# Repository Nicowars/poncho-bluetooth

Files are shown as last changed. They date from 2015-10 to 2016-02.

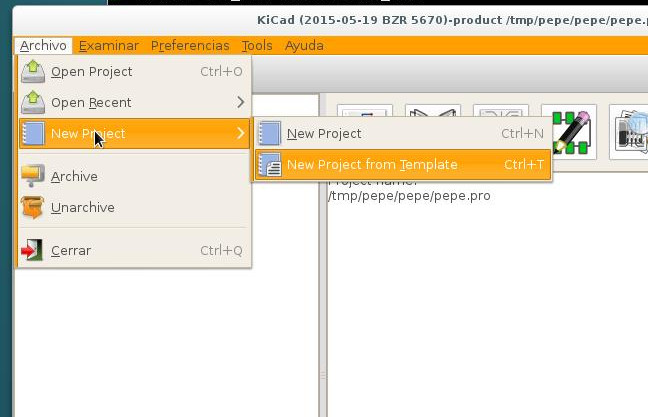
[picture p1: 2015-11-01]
Poncho/modelos/doc/screen1.jpg

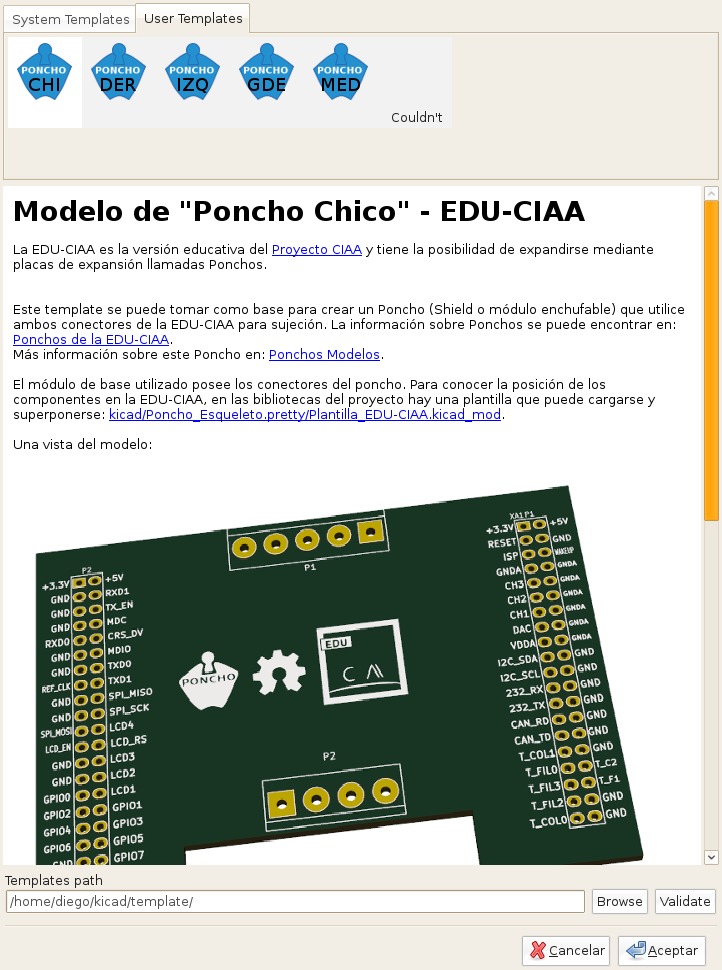
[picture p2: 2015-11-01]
Poncho/modelos/doc/screen5.jpg

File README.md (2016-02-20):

# poncho-bluetooth
Repositorio para el desarrollo de un Poncho que implementa Bluetooth para la EDU-CIAA

Para poder utilizarse correctamente el proyecto, debe sobreescribirse el archivo ubicado en /modules/drivers/cortexM4/lpc43xx/lpc4337/src/ciaaDriverDio.c del Firmware de la CIAA por el que esta incluido en projects/Firmware. Luego debe recompilarse el Firmware.

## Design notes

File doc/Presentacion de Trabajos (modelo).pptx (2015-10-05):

## Ingeniería en Computación Taller de Proyecto I [E0306]

Presentación Informe Inicial:
Título: Poncho Bluetooth
Fecha: 05/OCT/2015
Grupo 6
Integrantes:
1.- Laurella, Nicolás 4.- Solito, Manuel
2.- Morgillo, Gabriel 5.- Zubieta Battista, Jaime
3.- Muriel, Alex

## Presentación:

- 1.- Propuesta.
- 2.- Descripción del proyecto
- 3.- Materiales a utilizar
- 4.- Diagrama en Bloques del Sistema
- 5.- Explicación funcional
- 6.- Cronograma

Taller de Proyectos I

## Propuesta (1/2):

- Motivación:
Actualmente muchas aplicaciones requieren comunicación inalámbrica con dispositivos externos, por lo que consideramos fundamental agregar esta funcionalidad a la EDU-CIAA.
Por ejemplo el sistema de mando de un drone.

## Propuesta (2/2):

- Objetivos primarios: Diseñar e implementar una interfaz de bluetooth sobre una PCB compatible con la EDU-CIAA y desarrollar su respectivo controlador.
- Objetivos secundarios: Controlar los LEDs incluidos en la EDU-CIAA via Bluetooth desde una aplicación Android

## Materiales a utilizar (1/2):

Dispositivos:
- Chip Bluetooth RN4020 de Microchip
- U$S 18,50
- Proveedor: Elemon
- Versión Bluetooth 4.1
- Rango de Voltage 3.0V to 3.6V (3.3V)
- Rango de Temperatura: -30°C to 85°C
- Bajo consumo
  - Sleep <5.0 uA
  - Idle <1.5 mA
  - Active 16 mA a 0 dBm
- Interface UART
- Antena PCB incluida

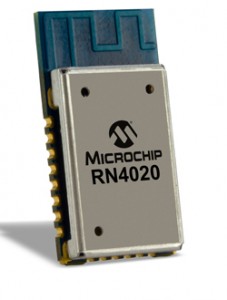
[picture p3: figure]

## Materiales a utilizar (2/2):

Componentes:
- 1 led verde
- 1 led azul
- 1 led rojo
- 3 resistencias de 330 Ohm
- 1 capacitor de Tantalio de 4,7 uF

## Diagrama de bloques (1/2)

PCB

RN4020

EDU-CIAA

UART

Otros

Referencia LEDs
- Led Rojo
Eventualidad
Encendido: Datos pendientes a ser recibidos
- Led Verde
Estado de conexión
Encendido: Conectado a un dispositivo
- Led Azul
Actividad
Encendido: Awake / en uso
Apagado: Sleep

LEDs

## Diagrama de bloques (2/2)

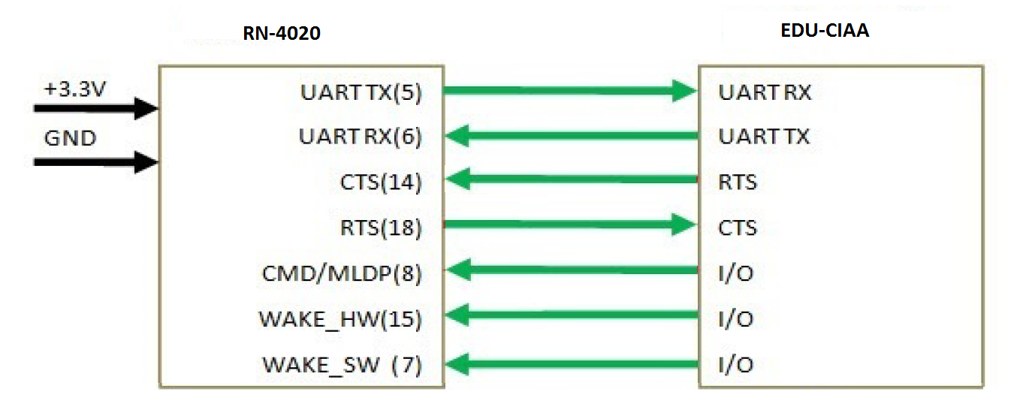
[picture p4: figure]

(RS232 RX)
(RS232 TX)

(GPIO)
(GPIO)
(GPIO)
(GPIO)
(GPIO)

Taller de Proyecto I

## Diagrama Esquemático:

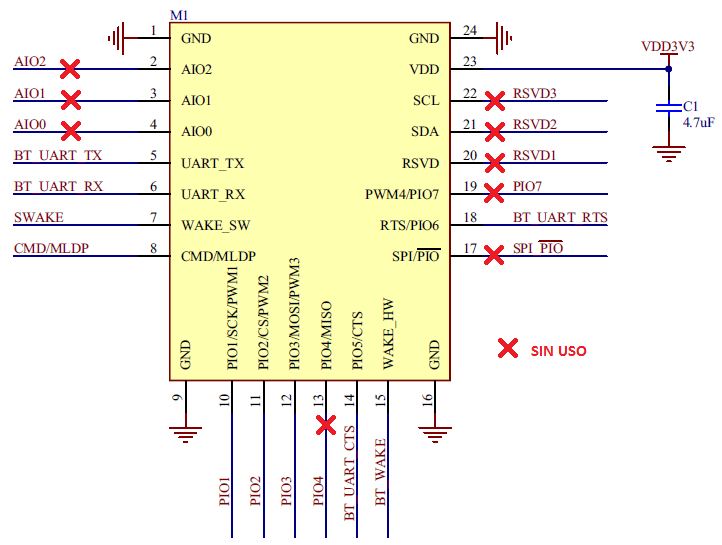
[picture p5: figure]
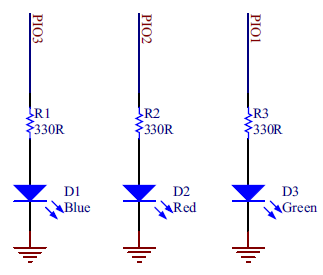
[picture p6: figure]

## Explicación funcional del Hardware y Software:

• Se realizará una aplicación Android para controlar vía Bluetooth los LEDs de la EDU-CIAA.
• La aplicación tendrá 3 botones para prender y apagar cada LED.
• Y además tendrá 3 barras deslizante para controlar la intensidad de cada color del LED RGB.

## Cronograma de Trabajo:

| Descripción | Fecha inicio | Fecha fin
Anteproyecto | Se analizan las propuestas y se fijan los objetivos | 10/08 | 16/08
Proyecto | Planeamiento y organización de las tareas a realizar | 17/08 | 13/09
Aprovisionamiento | Compra de los materiales requeridos | 14/09 | 09/10
Presentación del Proyecto | Presentación en clase del proyecto a realizar | 05/10 | 05/10
Diseño | Diseño de la placa PCB en KiCad® | 10/10 | 23/10
Prototipado | Implementación física de la unidad diseñada | 26/10 | 06/11
Controlador | Desarrollo del Firmware | 07/11 | 27/11
Testeo | Se prueba el correcto funcionamiento del Poncho | 28/11 | 04/12

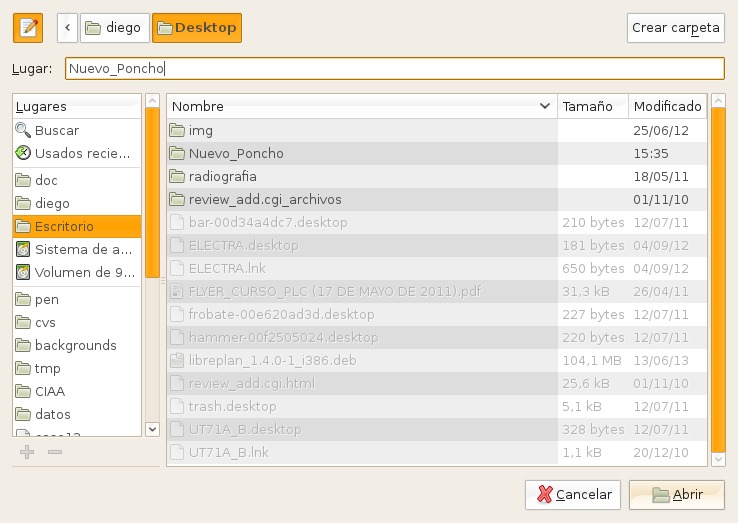
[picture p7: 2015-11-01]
Poncho/modelos/doc/screen2.jpg

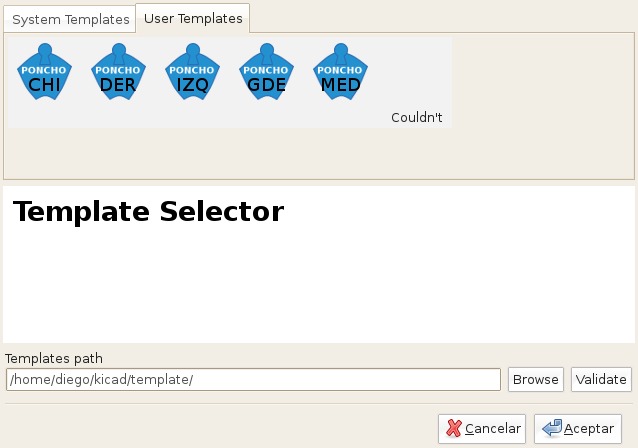
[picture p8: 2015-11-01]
Poncho/modelos/doc/screen4.jpg

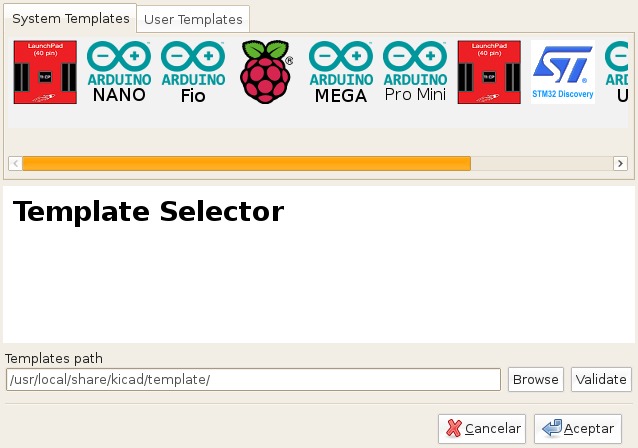
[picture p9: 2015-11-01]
Poncho/modelos/doc/screen3.jpg

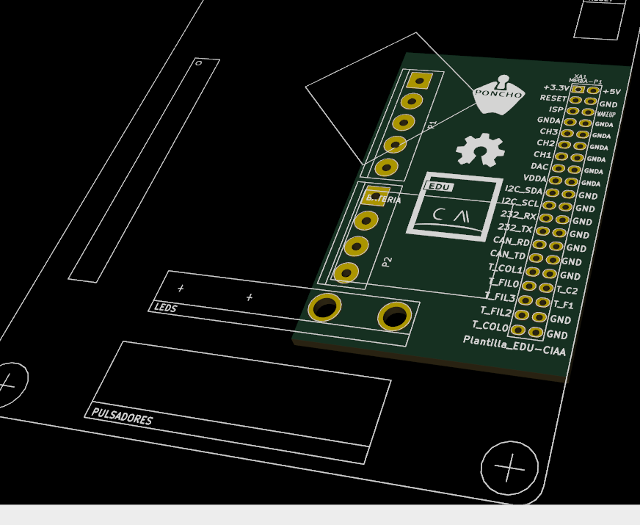
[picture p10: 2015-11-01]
Poncho/modelos/Poncho_Derecho/meta/ponchoF.png

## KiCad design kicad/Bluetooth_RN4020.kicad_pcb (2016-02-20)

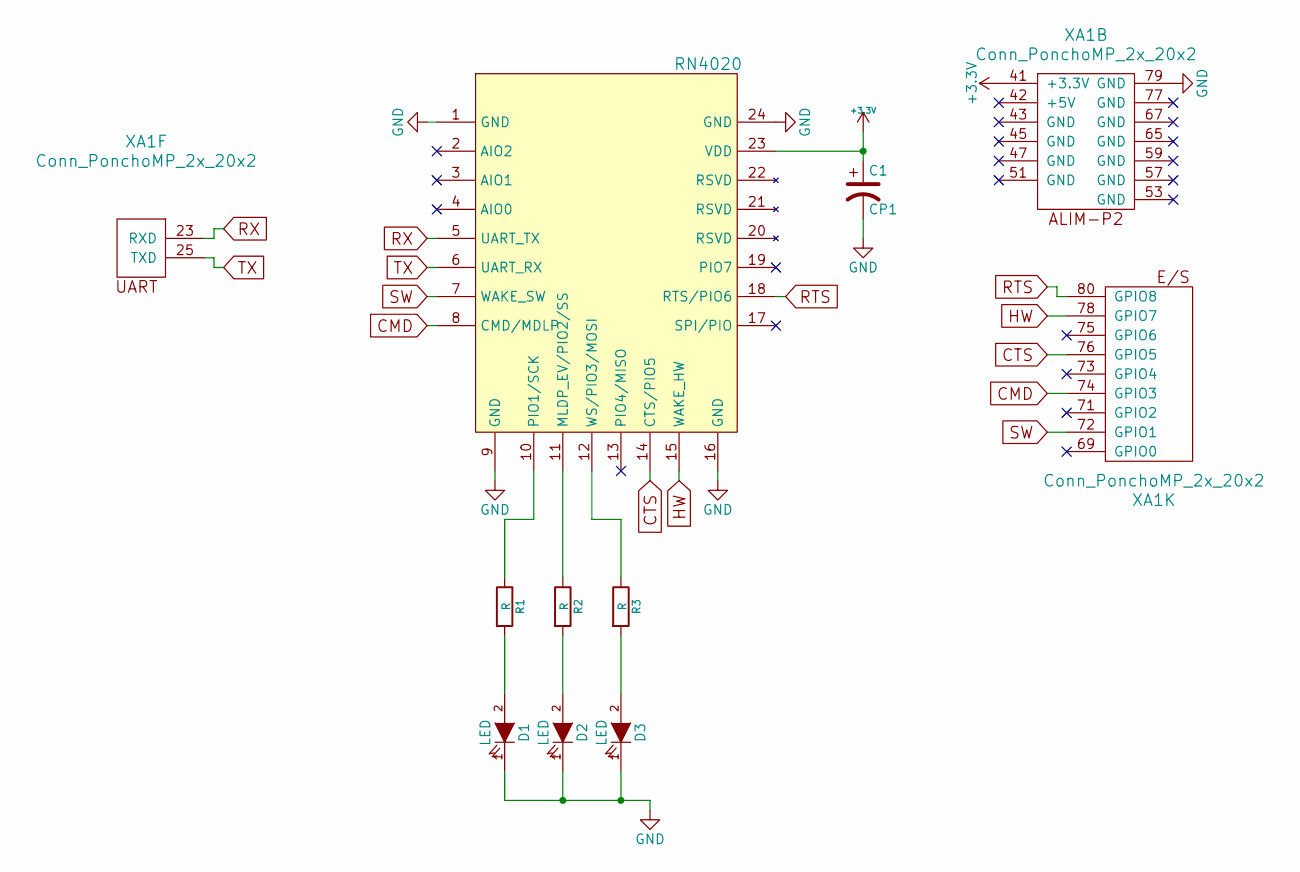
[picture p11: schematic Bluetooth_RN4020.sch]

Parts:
C1: CP1; TantalC_SizeB_EIA-3528_Reflow
D1, D2, D3: LED; LED-3MM
R1, R2, R3: R; R_1206
U1: RN4020
XA1: Conn_PonchoMP_2x_20x2

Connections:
+3V3: C1.1, U1.23 (VDD), XA1.41 (+3.3V)
CMD: U1.8 (CMD/MDLP), XA1.74 (GPIO3)
CTS: U1.14 (CTS/PIO5), XA1.76 (GPIO5)
GND: C1.2, D1.1 (K), D2.1 (K), D3.1 (K), U1.1 (GND), U1.9 (GND), U1.16 (GND), U1.24 (GND), XA1.79 (GND)
HW: U1.15 (WAKE_HW), XA1.78 (GPIO7)
unnamed: D1.2 (A), R1.2
unnamed: D2.2 (A), R2.2
unnamed: D3.2 (A), R3.2
unnamed: R1.1, U1.10 (PIO1/SCK)
unnamed: R2.1, U1.11 (MLDP_EV/PIO2/SS)
unnamed: R3.1, U1.12 (WS/PIO3/MOSI)
RTS: U1.18 (RTS/PIO6), XA1.80 (GPIO8)
RX: U1.5 (UART_TX), XA1.23 (RXD)
SW: U1.7 (WAKE_SW), XA1.72 (GPIO1)
TX: U1.6 (UART_RX), XA1.25 (TXD)

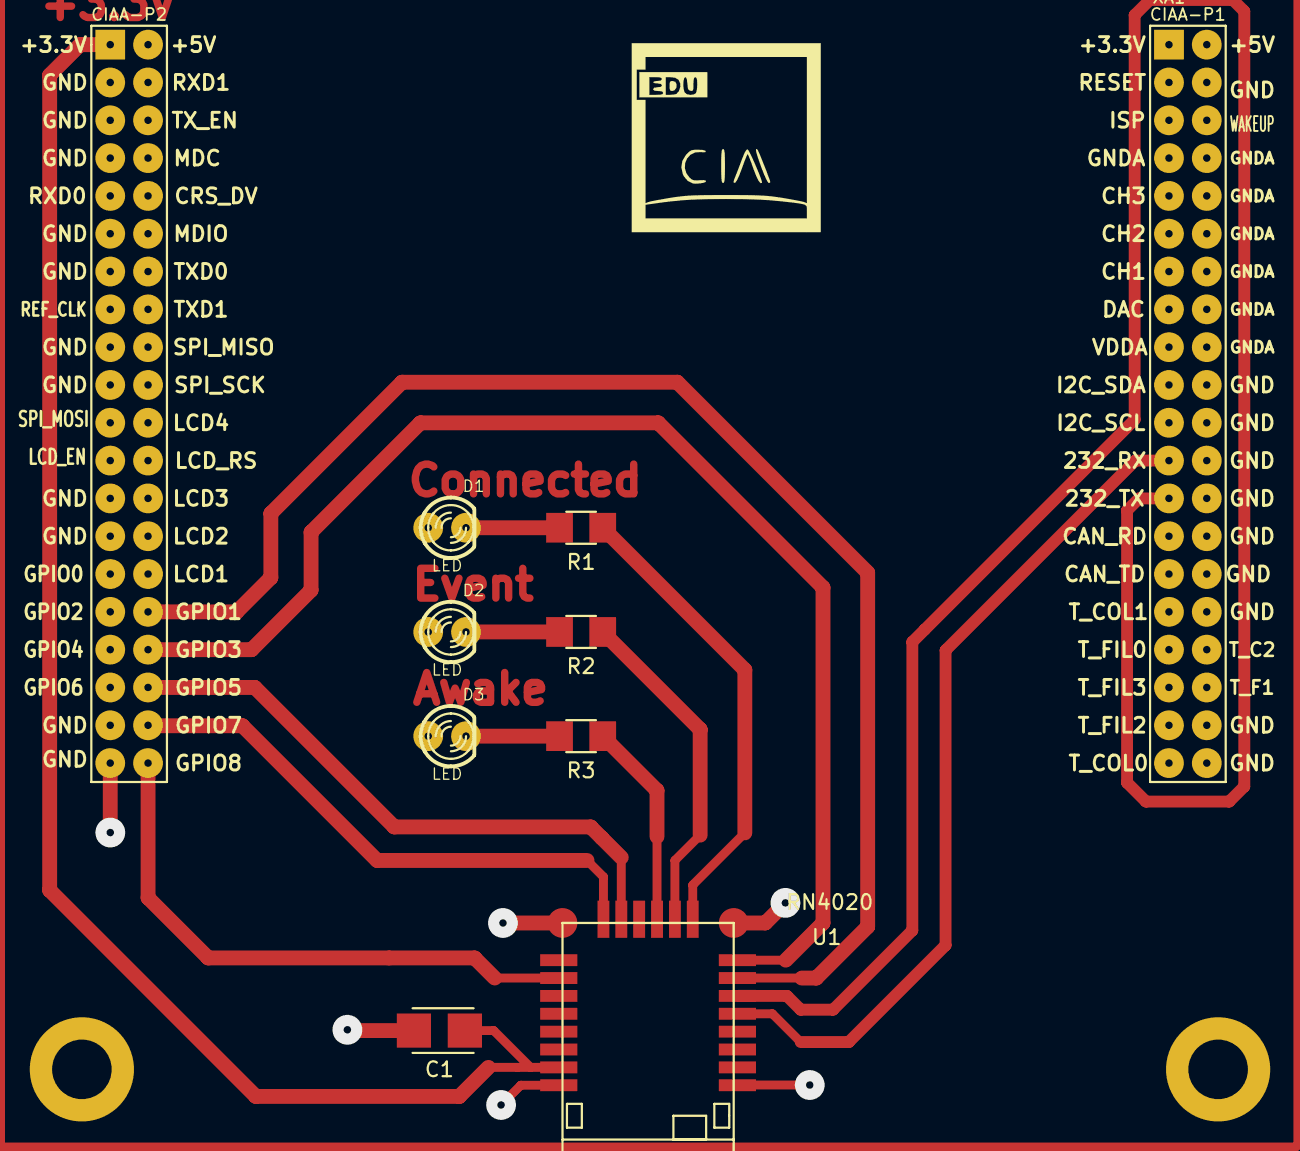
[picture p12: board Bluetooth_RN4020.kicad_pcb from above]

Board: 2 copper layers, 9 parts (0 on the bottom side), 15 nets.

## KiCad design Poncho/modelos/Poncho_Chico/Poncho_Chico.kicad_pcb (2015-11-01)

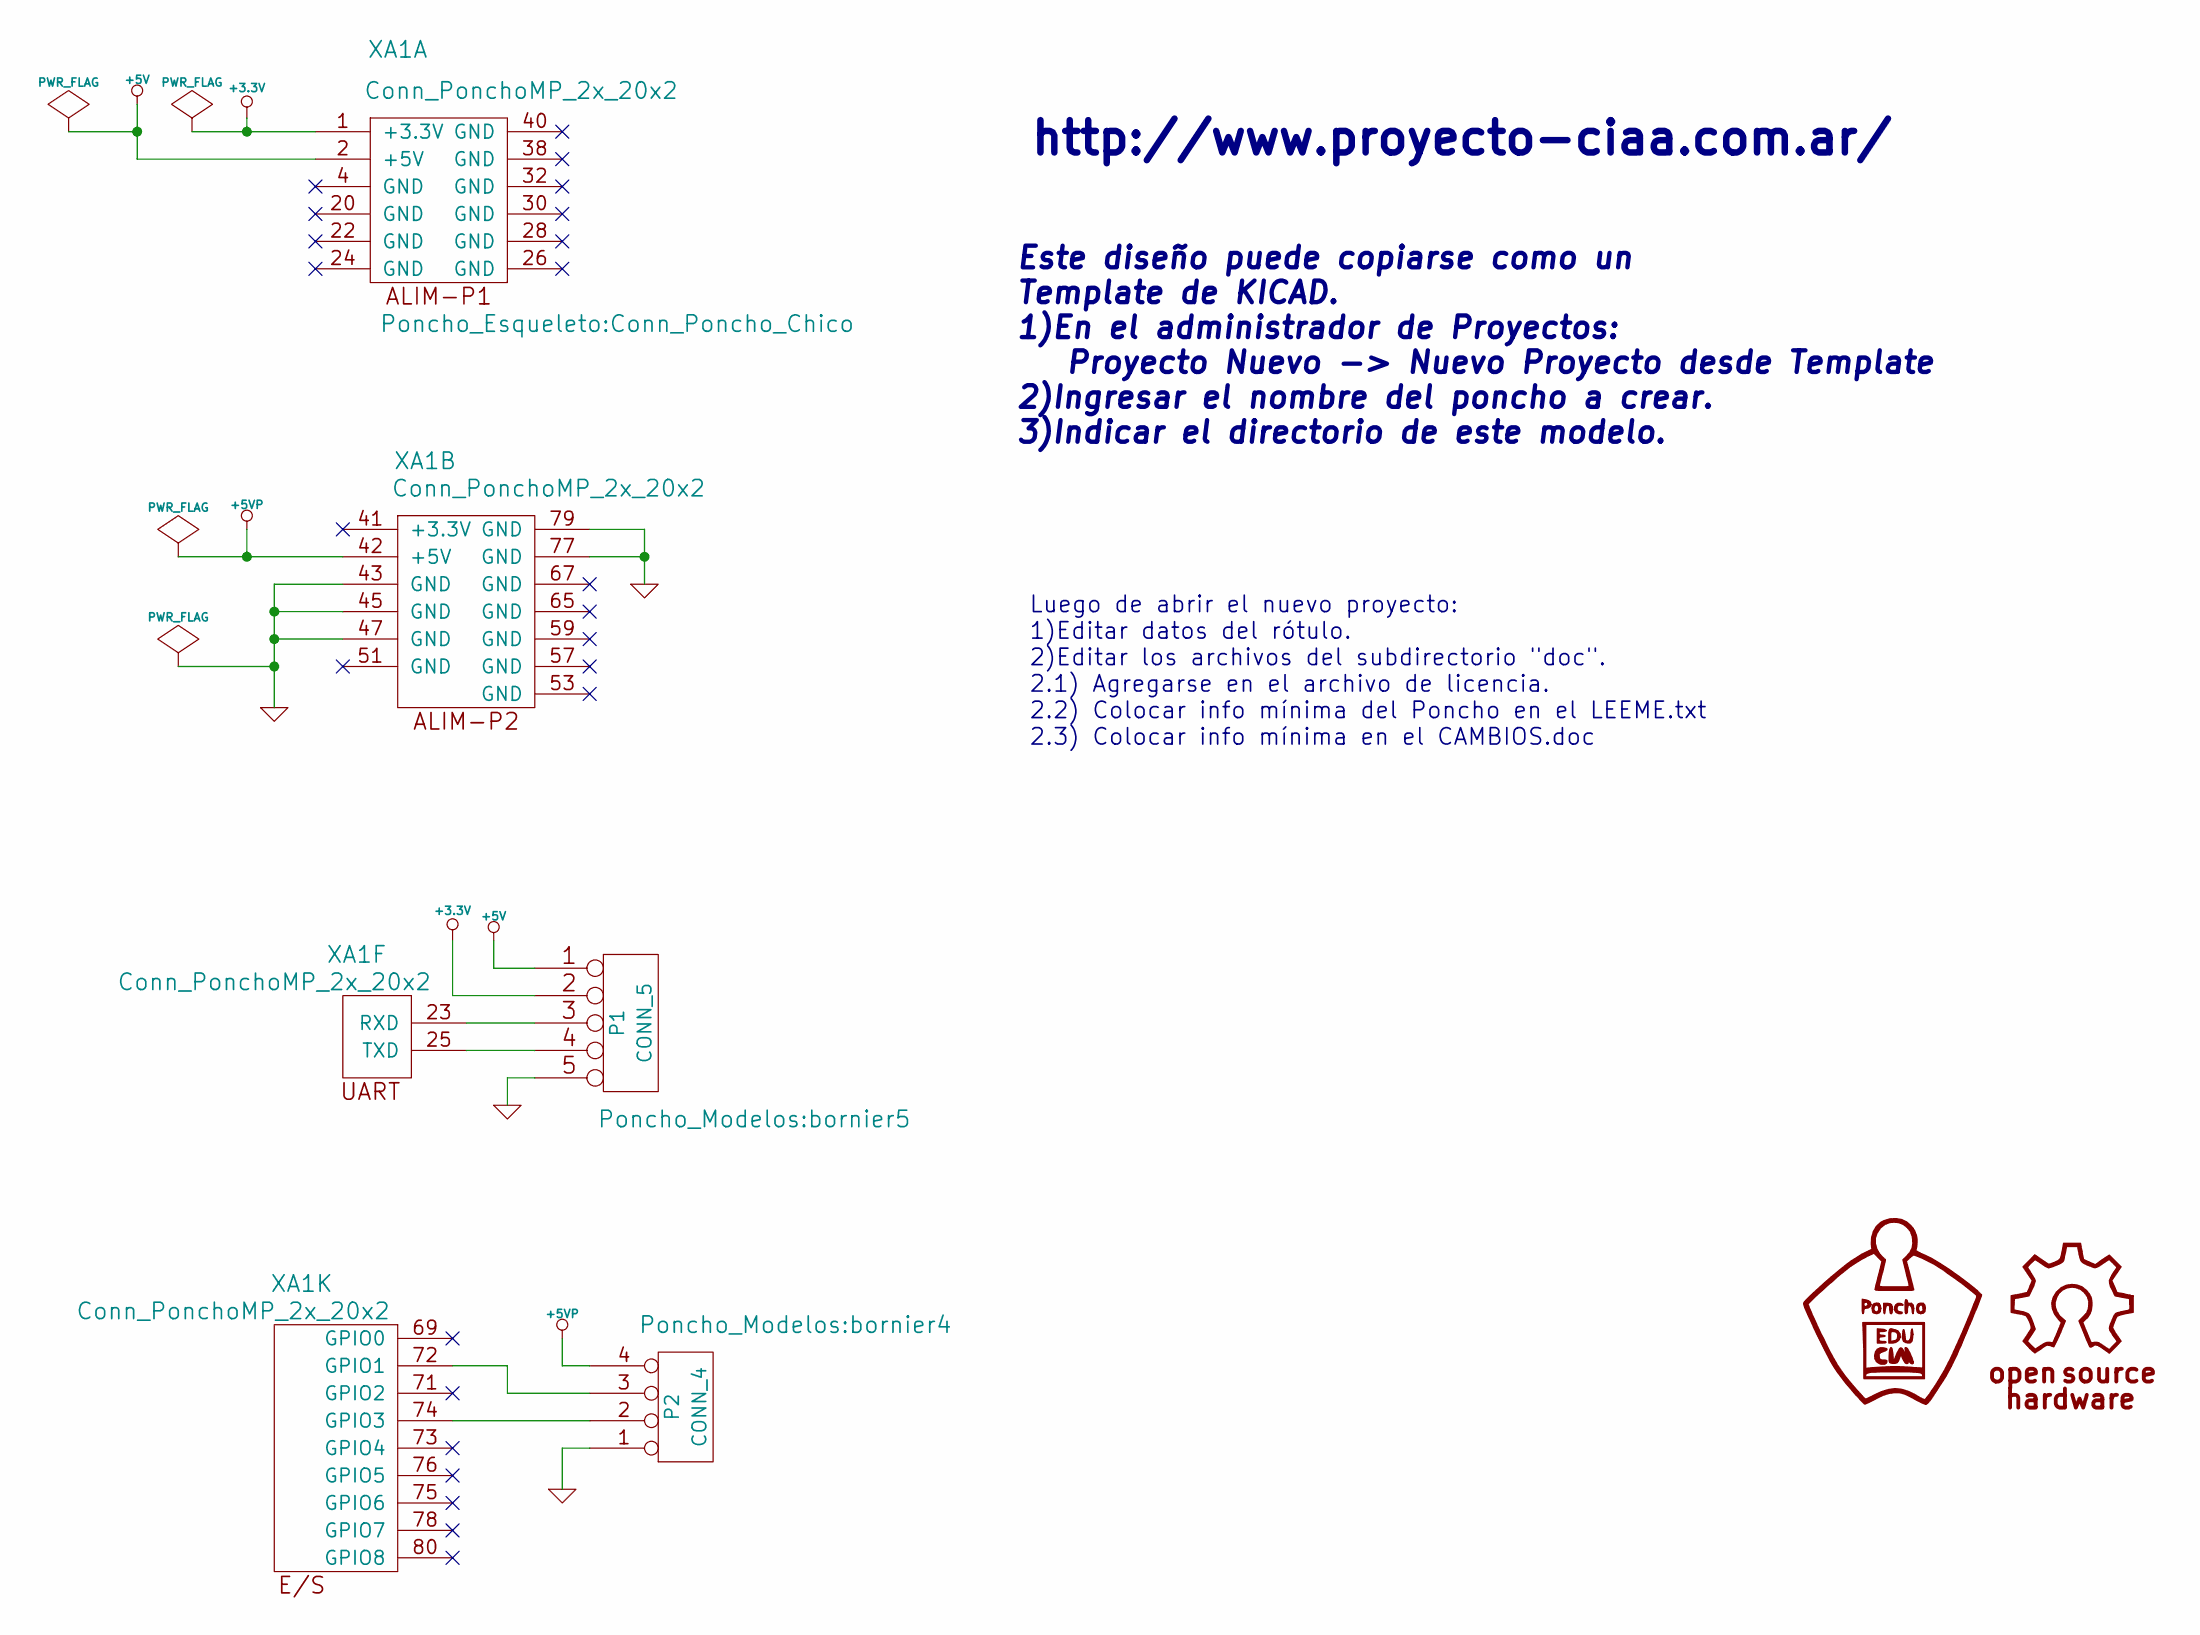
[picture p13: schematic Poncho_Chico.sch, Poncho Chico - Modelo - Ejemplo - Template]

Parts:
P1: CONN_5; bornier5
P2: CONN_4; bornier4
XA1: Conn_PonchoMP_2x_20x2; Conn_Poncho_Chico

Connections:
+3.3V: P1.2, XA1.1 (+3.3V)
+5V: P1.1, XA1.2 (+5V)
+5VP: P2.4, XA1.42 (+5V)
GND: P1.5, P2.1, XA1.43 (GND), XA1.45 (GND), XA1.47 (GND), XA1.77 (GND), XA1.79 (GND)
unnamed: P1.3, XA1.23 (RXD)
unnamed: P1.4, XA1.25 (TXD)
unnamed: P2.2, XA1.74 (GPIO3)
unnamed: P2.3, XA1.72 (GPIO1)

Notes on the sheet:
Este diseño puede copiarse como un Template de KICAD. 1)En el administrador de Proyectos: Proyecto Nuevo -> Nuevo Proyecto desde Template 2)Ingresar el nombre del poncho a crear. 3)Indicar el directorio de este modelo.
http://www.proyecto-ciaa.com.ar/
Luego de abrir el nuevo proyecto: 1)Editar datos del rótulo. 2)Editar los archivos del subdirectorio "doc". 2.1) Agregarse en el archivo de licencia. 2.2) Colocar info mínima del Poncho en el LEEME.txt 2.3) Colocar info mínima en el CAMBIOS.doc

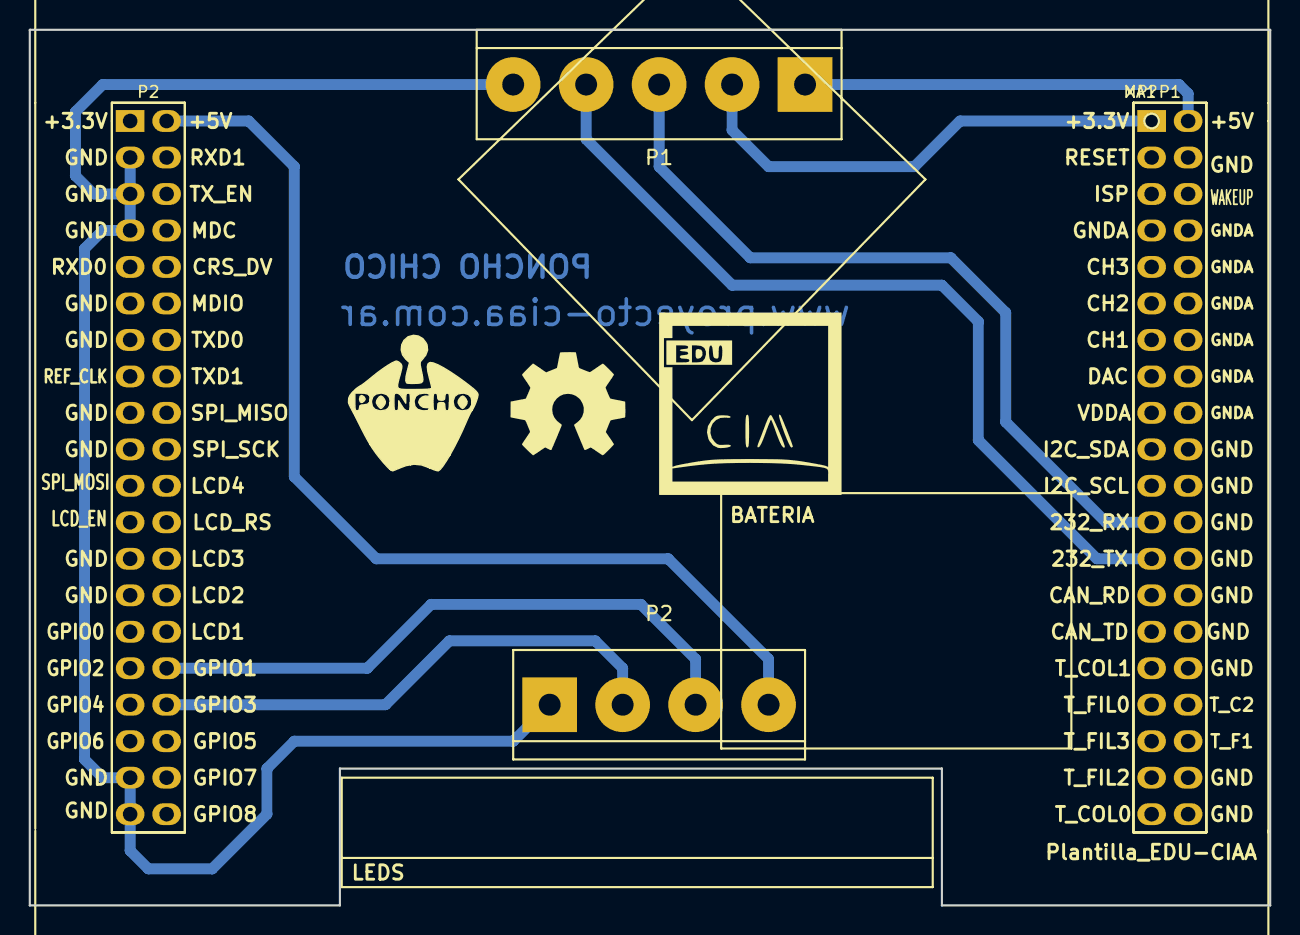
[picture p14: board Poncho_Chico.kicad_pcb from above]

Board: 2 copper layers, 86.4 x 61.0 mm, 5 parts (0 on the bottom side), 8 nets.

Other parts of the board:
G101: Logo_OSHWA
MP?: Plantilla_EDU-CIAA

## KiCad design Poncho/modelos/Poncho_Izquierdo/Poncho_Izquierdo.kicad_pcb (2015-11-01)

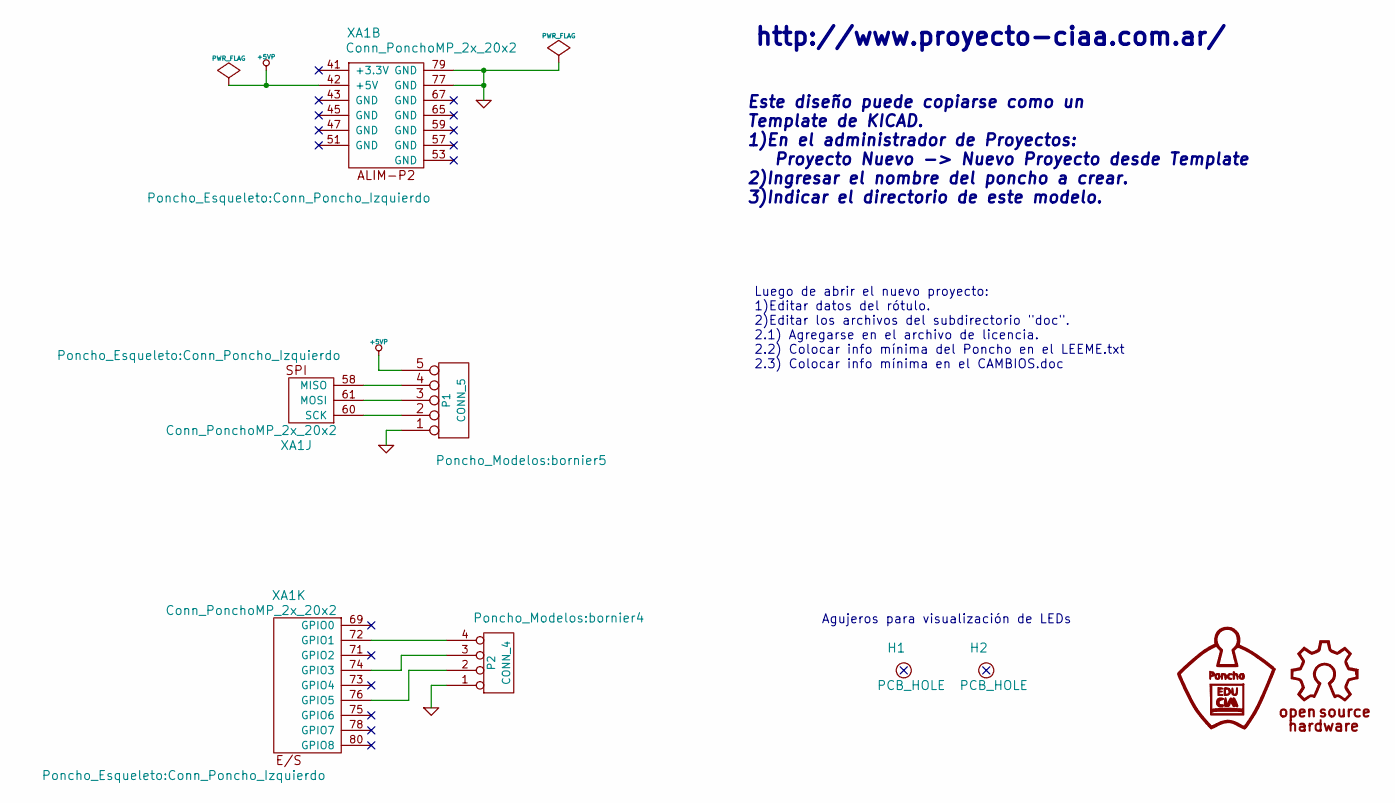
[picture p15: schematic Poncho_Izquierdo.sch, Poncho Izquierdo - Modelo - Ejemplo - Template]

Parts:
H1, H2: PCB_HOLE; Led_Hole
P1: CONN_5; bornier5
P2: CONN_4; bornier4
XA1: Conn_PonchoMP_2x_20x2; Conn_Poncho_Izquierdo

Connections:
+5VP: P1.5, XA1.42 (+5V)
GND: P1.1, P2.1, XA1.77 (GND), XA1.79 (GND)
unnamed: P1.2, XA1.60 (SCK)
unnamed: P1.3, XA1.61 (MOSI)
unnamed: P1.4, XA1.58 (MISO)
unnamed: P2.2, XA1.76 (GPIO5)
unnamed: P2.3, XA1.74 (GPIO3)
unnamed: P2.4, XA1.72 (GPIO1)

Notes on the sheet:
Este diseño puede copiarse como un Template de KICAD. 1)En el administrador de Proyectos: Proyecto Nuevo -> Nuevo Proyecto desde Template 2)Ingresar el nombre del poncho a crear. 3)Indicar el directorio de este modelo.
http://www.proyecto-ciaa.com.ar/
Luego de abrir el nuevo proyecto: 1)Editar datos del rótulo. 2)Editar los archivos del subdirectorio "doc". 2.1) Agregarse en el archivo de licencia. 2.2) Colocar info mínima del Poncho en el LEEME.txt 2.3) Colocar info mínima en el CAMBIOS.doc
Agujeros para visualización de LEDs

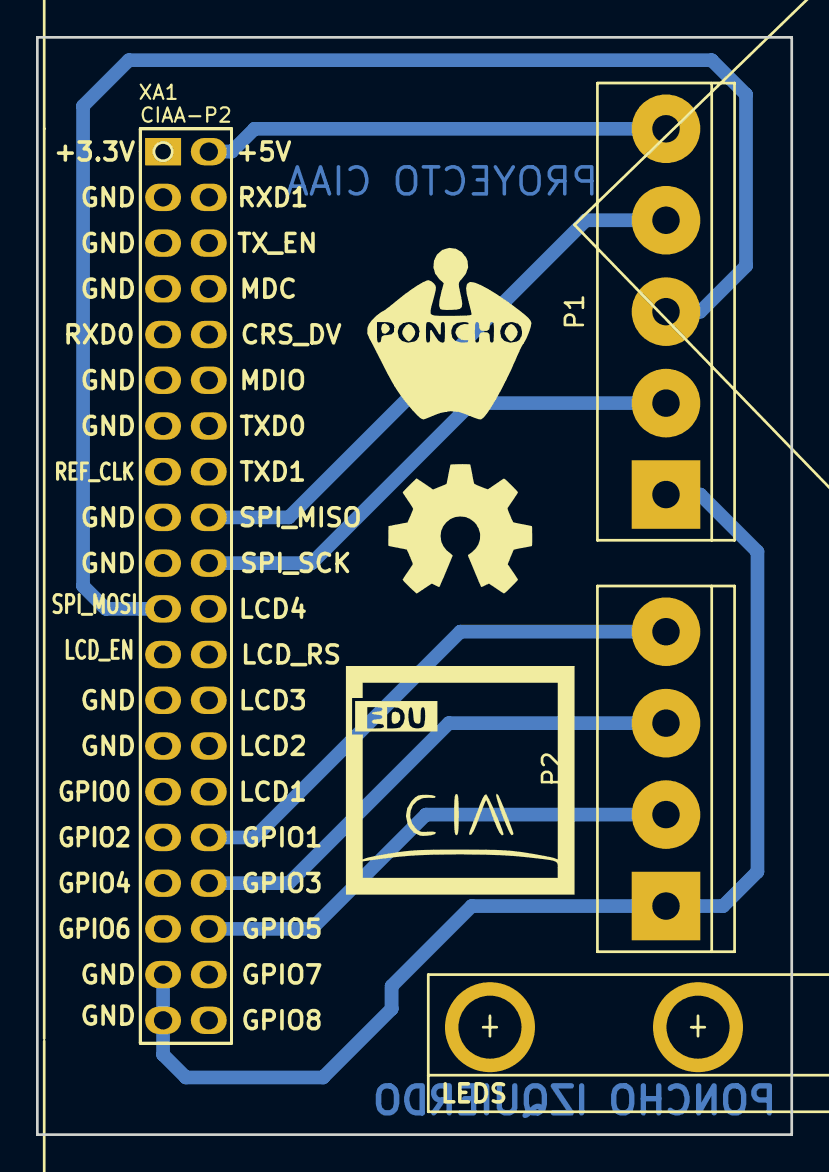
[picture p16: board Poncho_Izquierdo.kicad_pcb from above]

Board: 2 copper layers, 41.9 x 61.0 mm, 7 parts (0 on the bottom side), 8 nets.

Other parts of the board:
G101: Logo_OSHWA
MP1: Plantilla_EDU-CIAA

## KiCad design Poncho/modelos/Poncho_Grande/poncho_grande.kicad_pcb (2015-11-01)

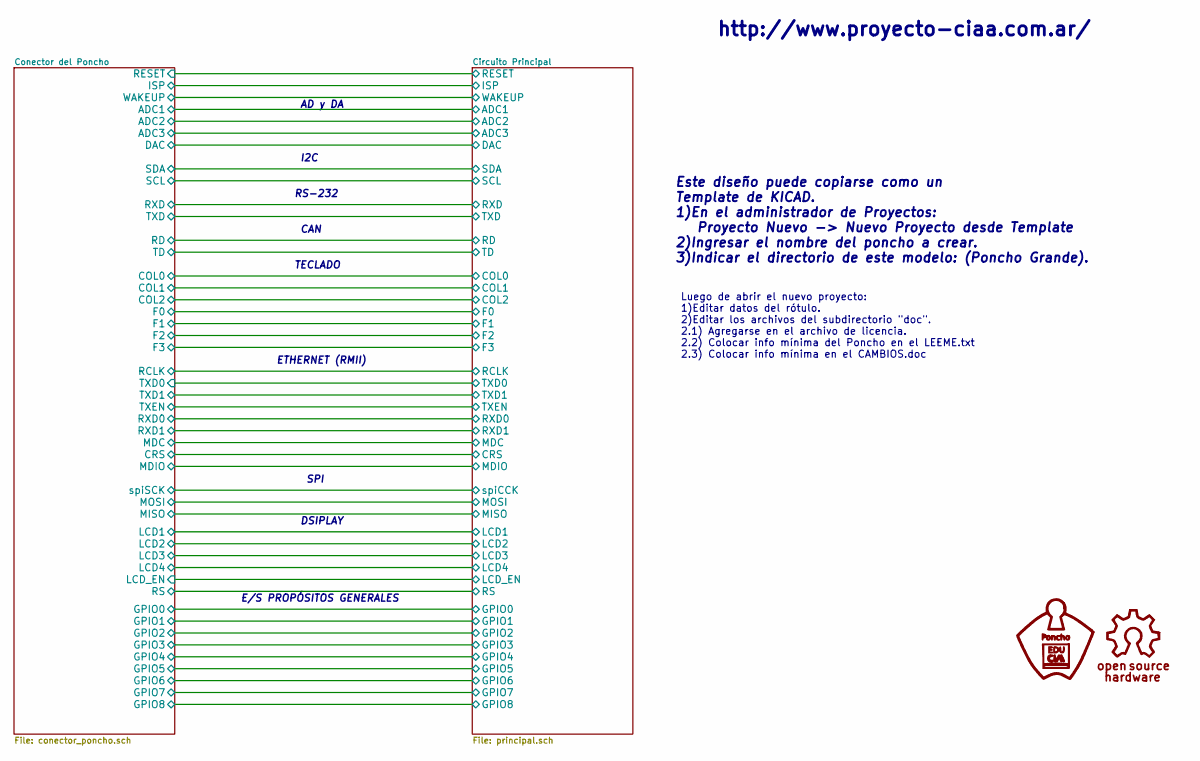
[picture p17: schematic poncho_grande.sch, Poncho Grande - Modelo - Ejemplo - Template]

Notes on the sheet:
AD y DA
I2C
RS-232
CAN
TECLADO
ETHERNET (RMII)
SPI
DSIPLAY
E/S PROPÓSITOS GENERALES
Este diseño puede copiarse como un Template de KICAD. 1)En el administrador de Proyectos: Proyecto Nuevo -> Nuevo Proyecto desde Template 2)Ingresar el nombre del poncho a crear. 3)Indicar el directorio de este modelo: (Poncho Grande).
http://www.proyecto-ciaa.com.ar/
Luego de abrir el nuevo proyecto: 1)Editar datos del rótulo. 2)Editar los archivos del subdirectorio "doc". 2.1) Agregarse en el archivo de licencia. 2.2) Colocar info mínima del Poncho en el LEEME.txt 2.3) Colocar info mínima en el CAMBIOS.doc

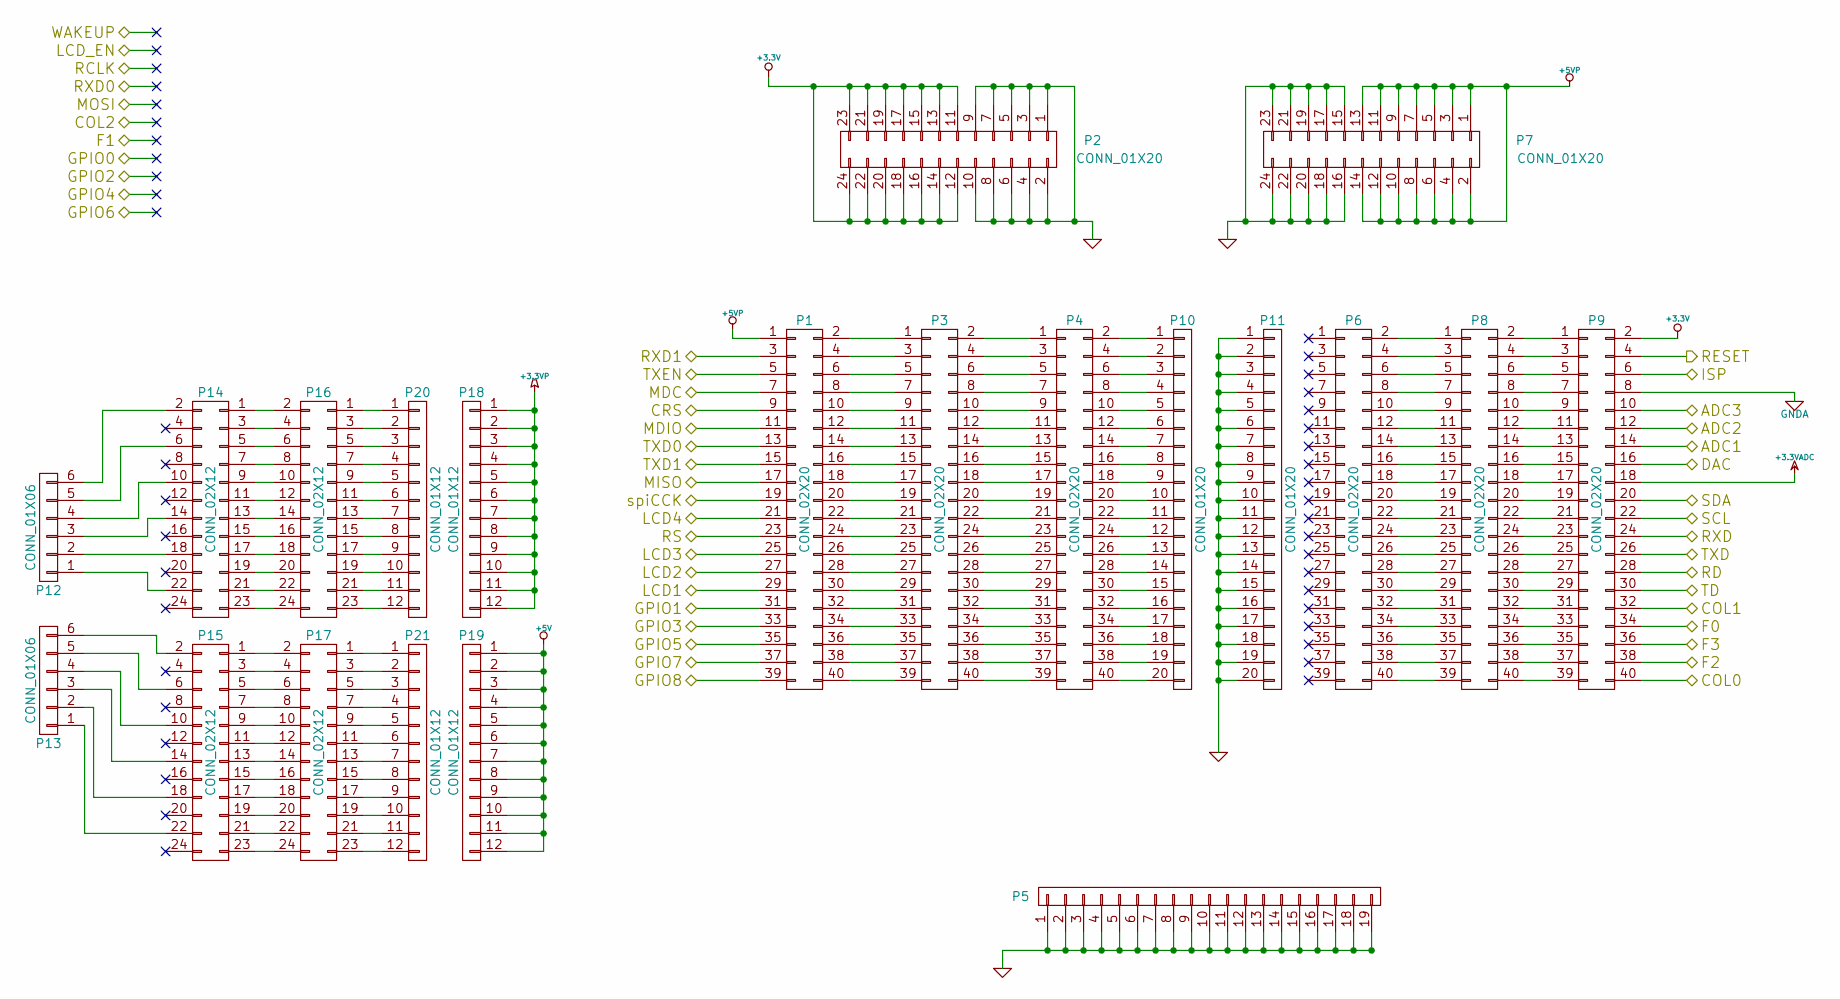
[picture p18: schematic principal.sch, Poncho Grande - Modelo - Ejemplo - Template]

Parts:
P1, P3, P4, P6, P8, P9: CONN_02X20; Pin_Header_Straight_2x20
P2, P7: CONN_01X20; Pin_Header_Straight_2x12
P5: CONN_01X19; Pin_Header_Straight_1x19
P10, P11: CONN_01X20; Pin_Header_Straight_1x20
P12, P13: CONN_01X06; bornier6
P14, P15, P16, P17: CONN_02X12; Pin_Header_Straight_2x12
P18, P19, P20, P21: CONN_01X12; Pin_Header_Straight_1x12

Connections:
+3.3V: P2.11, P2.12, P2.13, P2.14, P2.15, P2.16, P2.17, P2.18, P2.19, P2.20, P2.21, P2.22, P2.23, P2.24, P9.2; also elsewhere on the board
+3.3VADC: P9.18; also elsewhere on the board
+3.3VP: P18.1, P18.2, P18.3, P18.4, P18.5, P18.6, P18.7, P18.8, P18.9, P18.10, P18.11, P18.12; also elsewhere on the board
+5V: P19.1, P19.2, P19.3, P19.4, P19.5, P19.6, P19.7, P19.8, P19.9, P19.10, P19.11, P19.12; also elsewhere on the board
+5VP: P1.1, P7.1, P7.2, P7.3, P7.4, P7.5, P7.6, P7.7, P7.8, P7.9, P7.10, P7.11, P7.12, P7.13, P7.14; also elsewhere on the board
/Circuito Principal/ADC1: P9.14; also elsewhere on the board
/Circuito Principal/ADC2: P9.12; also elsewhere on the board
/Circuito Principal/ADC3: P9.10; also elsewhere on the board
/Circuito Principal/COL0: P9.40; also elsewhere on the board
/Circuito Principal/COL1: P9.32; also elsewhere on the board
/Circuito Principal/CRS: P1.9; also elsewhere on the board
/Circuito Principal/DAC: P9.16; also elsewhere on the board
/Circuito Principal/F0: P9.34; also elsewhere on the board
/Circuito Principal/F2: P9.38; also elsewhere on the board
/Circuito Principal/F3: P9.36; also elsewhere on the board
/Circuito Principal/GPIO1: P1.31; also elsewhere on the board
/Circuito Principal/GPIO3: P1.33; also elsewhere on the board
/Circuito Principal/GPIO5: P1.35; also elsewhere on the board
/Circuito Principal/GPIO7: P1.37; also elsewhere on the board
/Circuito Principal/GPIO8: P1.39; also elsewhere on the board
/Circuito Principal/ISP: P9.6; also elsewhere on the board
/Circuito Principal/LCD1: P1.29; also elsewhere on the board
/Circuito Principal/LCD2: P1.27; also elsewhere on the board
/Circuito Principal/LCD3: P1.25; also elsewhere on the board
/Circuito Principal/LCD4: P1.21; also elsewhere on the board
/Circuito Principal/MDC: P1.7; also elsewhere on the board
/Circuito Principal/MDIO: P1.11; also elsewhere on the board
/Circuito Principal/MISO: P1.17; also elsewhere on the board
/Circuito Principal/RD: P9.28; also elsewhere on the board
/Circuito Principal/RESET: P9.4; also elsewhere on the board
/Circuito Principal/RS: P1.23; also elsewhere on the board
/Circuito Principal/RXD: P9.24; also elsewhere on the board
/Circuito Principal/RXD1: P1.3; also elsewhere on the board
/Circuito Principal/SCL: P9.22; also elsewhere on the board
/Circuito Principal/SDA: P9.20; also elsewhere on the board
/Circuito Principal/TD: P9.30; also elsewhere on the board
/Circuito Principal/TXD: P9.26; also elsewhere on the board
/Circuito Principal/TXD0: P1.13; also elsewhere on the board
/Circuito Principal/TXD1: P1.15; also elsewhere on the board
/Circuito Principal/TXEN: P1.5; also elsewhere on the board
/Circuito Principal/spiCCK: P1.19; also elsewhere on the board
GND: P2.1, P2.2, P2.3, P2.4, P2.5, P2.6, P2.7, P2.8, P2.9, P2.10, P5.1, P5.2, P5.3, P5.4, P5.5, P5.6, P5.7, P5.8, P5.9, P5.10, P5.11, P5.12, P5.13, P5.14, P5.15, P5.16, P5.17, P5.18, P5.19, P7.15, P7.16, P7.17, P7.18, P7.19, P7.20, P7.21, P7.22, P7.23, P7.24, P11.1, P11.2, P11.3, P11.4, P11.5, P11.6, P11.7, P11.8, P11.9, P11.10, P11.11, P11.12, P11.13, P11.14, P11.15, P11.16, P11.17, P11.18, P11.19, P11.20; also elsewhere on the board
GNDA: P9.8; also elsewhere on the board
unnamed: P1.2, P3.1
unnamed: P1.4, P3.3
unnamed: P1.6, P3.5
unnamed: P1.8, P3.7
unnamed: P1.10, P3.9
unnamed: P1.12, P3.11
unnamed: P1.14, P3.13
unnamed: P1.16, P3.15
unnamed: P1.18, P3.17
unnamed: P1.20, P3.19
unnamed: P1.22, P3.21
unnamed: P1.24, P3.23
unnamed: P1.26, P3.25
unnamed: P1.28, P3.27
unnamed: P1.30, P3.29
unnamed: P1.32, P3.31
unnamed: P1.34, P3.33
unnamed: P1.36, P3.35
unnamed: P1.38, P3.37
unnamed: P1.40, P3.39
unnamed: P3.2, P4.1
unnamed: P3.4, P4.3
unnamed: P3.6, P4.5
unnamed: P3.8, P4.7
unnamed: P3.10, P4.9
unnamed: P3.12, P4.11
unnamed: P3.14, P4.13
unnamed: P3.16, P4.15
unnamed: P3.18, P4.17
unnamed: P3.20, P4.19
unnamed: P3.22, P4.21
unnamed: P3.24, P4.23
unnamed: P3.26, P4.25
unnamed: P3.28, P4.27
unnamed: P3.30, P4.29
unnamed: P3.32, P4.31
unnamed: P3.34, P4.33
unnamed: P3.36, P4.35
unnamed: P3.38, P4.37
unnamed: P3.40, P4.39
unnamed: P6.2, P8.1
unnamed: P6.4, P8.3
unnamed: P6.6, P8.5
unnamed: P6.8, P8.7
unnamed: P6.10, P8.9
unnamed: P6.12, P8.11
unnamed: P6.14, P8.13
unnamed: P6.16, P8.15
unnamed: P6.18, P8.17
unnamed: P6.20, P8.19
unnamed: P6.22, P8.21
unnamed: P6.24, P8.23
unnamed: P6.26, P8.25
unnamed: P6.28, P8.27
unnamed: P6.30, P8.29
unnamed: P6.32, P8.31
unnamed: P6.34, P8.33
unnamed: P6.36, P8.35
unnamed: P6.38, P8.37
unnamed: P6.40, P8.39
unnamed: P8.2, P9.1
unnamed: P8.4, P9.3
unnamed: P8.6, P9.5
unnamed: P8.8, P9.7
unnamed: P8.10, P9.9
unnamed: P8.12, P9.11
unnamed: P8.14, P9.13
unnamed: P8.16, P9.15
unnamed: P8.18, P9.17
unnamed: P8.20, P9.19
unnamed: P8.22, P9.21
unnamed: P8.24, P9.23
unnamed: P8.26, P9.25
unnamed: P8.28, P9.27
unnamed: P8.30, P9.29
unnamed: P8.32, P9.31
unnamed: P8.34, P9.33
unnamed: P8.36, P9.35
unnamed: P8.38, P9.37
unnamed: P8.40, P9.39
unnamed: P4.2, P10.1
unnamed: P4.4, P10.2
unnamed: P4.6, P10.3
unnamed: P4.8, P10.4
unnamed: P4.10, P10.5
unnamed: P4.12, P10.6
unnamed: P4.14, P10.7
unnamed: P4.16, P10.8
unnamed: P4.18, P10.9
unnamed: P4.20, P10.10
unnamed: P4.22, P10.11
unnamed: P4.24, P10.12
unnamed: P4.26, P10.13
unnamed: P4.28, P10.14
unnamed: P4.30, P10.15
unnamed: P4.32, P10.16
unnamed: P4.34, P10.17
unnamed: P4.36, P10.18
unnamed: P4.38, P10.19
unnamed: P4.40, P10.20
unnamed: P12.1, P14.22
unnamed: P12.2, P14.18
unnamed: P12.3, P14.14
unnamed: P12.4, P14.10
unnamed: P12.5, P14.6
unnamed: P12.6, P14.2
unnamed: P13.1, P15.22
unnamed: P13.2, P15.18
unnamed: P13.3, P15.14
unnamed: P13.4, P15.10
unnamed: P13.5, P15.6
unnamed: P13.6, P15.2
unnamed: P14.1, P16.2
unnamed: P14.3, P16.4
unnamed: P14.5, P16.6
unnamed: P14.7, P16.8
unnamed: P14.9, P16.10
unnamed: P14.11, P16.12
unnamed: P14.13, P16.14
unnamed: P14.15, P16.16
unnamed: P14.17, P16.18
unnamed: P14.19, P16.20
unnamed: P14.21, P16.22
unnamed: P14.23, P16.24
unnamed: P15.1, P17.2
unnamed: P15.3, P17.4
unnamed: P15.5, P17.6
unnamed: P15.7, P17.8
unnamed: P15.9, P17.10
unnamed: P15.11, P17.12
unnamed: P15.13, P17.14
unnamed: P15.15, P17.16
unnamed: P15.17, P17.18
unnamed: P15.19, P17.20
unnamed: P15.21, P17.22
unnamed: P15.23, P17.24
unnamed: P16.1, P20.1
unnamed: P16.3, P20.2
unnamed: P16.5, P20.3
unnamed: P16.7, P20.4
unnamed: P16.9, P20.5
unnamed: P16.11, P20.6
unnamed: P16.13, P20.7
unnamed: P16.15, P20.8
unnamed: P16.17, P20.9
unnamed: P16.19, P20.10
unnamed: P16.21, P20.11
unnamed: P16.23, P20.12
unnamed: P17.1, P21.1
unnamed: P17.3, P21.2
unnamed: P17.5, P21.3
unnamed: P17.7, P21.4
unnamed: P17.9, P21.5
unnamed: P17.11, P21.6
unnamed: P17.13, P21.7
unnamed: P17.15, P21.8
unnamed: P17.17, P21.9
unnamed: P17.19, P21.10
unnamed: P17.21, P21.11
unnamed: P17.23, P21.12

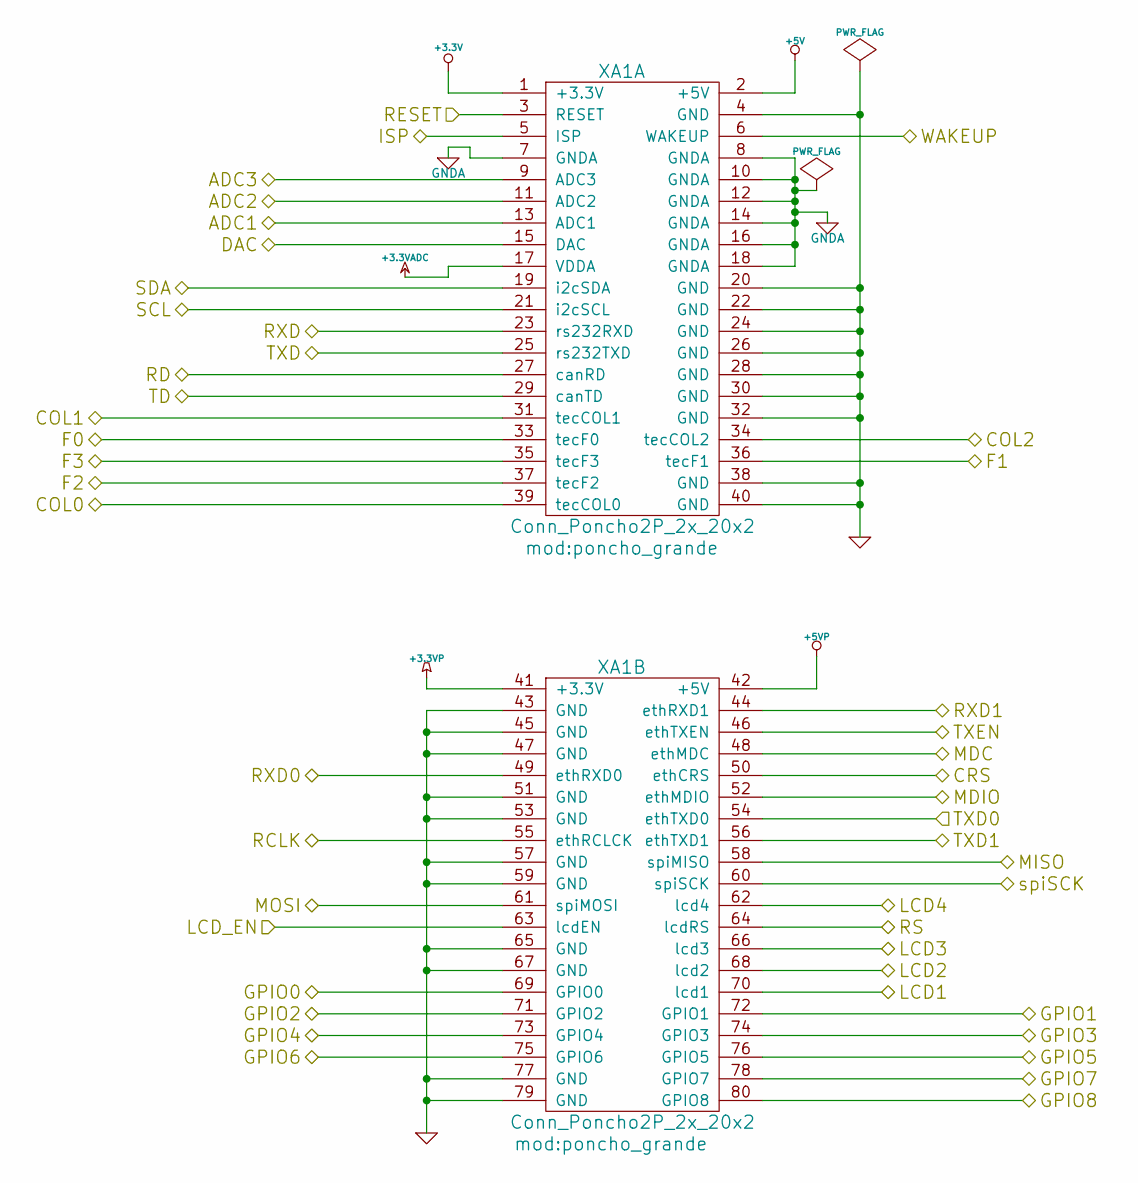
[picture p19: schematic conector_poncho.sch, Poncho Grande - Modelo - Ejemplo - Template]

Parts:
XA1: Conn_Poncho2P_2x_20x2; poncho_grande

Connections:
+3.3V: XA1.1 (+3.3V); also elsewhere on the board
+3.3VADC: XA1.17 (VDDA); also elsewhere on the board
+3.3VP: XA1.41 (+3.3V); also elsewhere on the board
+5V: XA1.2 (+5V); also elsewhere on the board
+5VP: XA1.42 (+5V); also elsewhere on the board
/Circuito Principal/ADC1: XA1.13 (ADC1); also elsewhere on the board
/Circuito Principal/ADC2: XA1.11 (ADC2); also elsewhere on the board
/Circuito Principal/ADC3: XA1.9 (ADC3); also elsewhere on the board
/Circuito Principal/COL0: XA1.39 (tecCOL0); also elsewhere on the board
/Circuito Principal/COL1: XA1.31 (tecCOL1); also elsewhere on the board
/Circuito Principal/CRS: XA1.50 (ethCRS); also elsewhere on the board
/Circuito Principal/DAC: XA1.15 (DAC); also elsewhere on the board
/Circuito Principal/F0: XA1.33 (tecF0); also elsewhere on the board
/Circuito Principal/F2: XA1.37 (tecF2); also elsewhere on the board
/Circuito Principal/F3: XA1.35 (tecF3); also elsewhere on the board
/Circuito Principal/GPIO1: XA1.72 (GPIO1); also elsewhere on the board
/Circuito Principal/GPIO3: XA1.74 (GPIO3); also elsewhere on the board
/Circuito Principal/GPIO5: XA1.76 (GPIO5); also elsewhere on the board
/Circuito Principal/GPIO7: XA1.78 (GPIO7); also elsewhere on the board
/Circuito Principal/GPIO8: XA1.80 (GPIO8); also elsewhere on the board
/Circuito Principal/ISP: XA1.5 (ISP); also elsewhere on the board
/Circuito Principal/LCD1: XA1.70 (lcd1); also elsewhere on the board
/Circuito Principal/LCD2: XA1.68 (lcd2); also elsewhere on the board
/Circuito Principal/LCD3: XA1.66 (lcd3); also elsewhere on the board
/Circuito Principal/LCD4: XA1.62 (lcd4); also elsewhere on the board
/Circuito Principal/MDC: XA1.48 (ethMDC); also elsewhere on the board
/Circuito Principal/MDIO: XA1.52 (ethMDIO); also elsewhere on the board
/Circuito Principal/MISO: XA1.58 (spiMISO); also elsewhere on the board
/Circuito Principal/RD: XA1.27 (canRD); also elsewhere on the board
/Circuito Principal/RESET: XA1.3 (RESET); also elsewhere on the board
/Circuito Principal/RS: XA1.64 (lcdRS); also elsewhere on the board
/Circuito Principal/RXD: XA1.23 (rs232RXD); also elsewhere on the board
/Circuito Principal/RXD1: XA1.44 (ethRXD1); also elsewhere on the board
/Circuito Principal/SCL: XA1.21 (i2cSCL); also elsewhere on the board
/Circuito Principal/SDA: XA1.19 (i2cSDA); also elsewhere on the board
/Circuito Principal/TD: XA1.29 (canTD); also elsewhere on the board
/Circuito Principal/TXD: XA1.25 (rs232TXD); also elsewhere on the board
/Circuito Principal/TXD0: XA1.54 (ethTXD0); also elsewhere on the board
/Circuito Principal/TXD1: XA1.56 (ethTXD1); also elsewhere on the board
/Circuito Principal/TXEN: XA1.46 (ethTXEN); also elsewhere on the board
/Circuito Principal/spiCCK: XA1.60 (spiSCK); also elsewhere on the board
GND: XA1.4 (GND), XA1.20 (GND), XA1.22 (GND), XA1.24 (GND), XA1.26 (GND), XA1.28 (GND), XA1.30 (GND), XA1.32 (GND), XA1.38 (GND), XA1.40 (GND), XA1.43 (GND), XA1.45 (GND), XA1.47 (GND), XA1.51 (GND), XA1.53 (GND), XA1.57 (GND), XA1.59 (GND), XA1.65 (GND), XA1.67 (GND), XA1.77 (GND), XA1.79 (GND); also elsewhere on the board
GNDA: XA1.7 (GNDA), XA1.8 (GNDA), XA1.10 (GNDA), XA1.12 (GNDA), XA1.14 (GNDA), XA1.16 (GNDA), XA1.18 (GNDA); also elsewhere on the board

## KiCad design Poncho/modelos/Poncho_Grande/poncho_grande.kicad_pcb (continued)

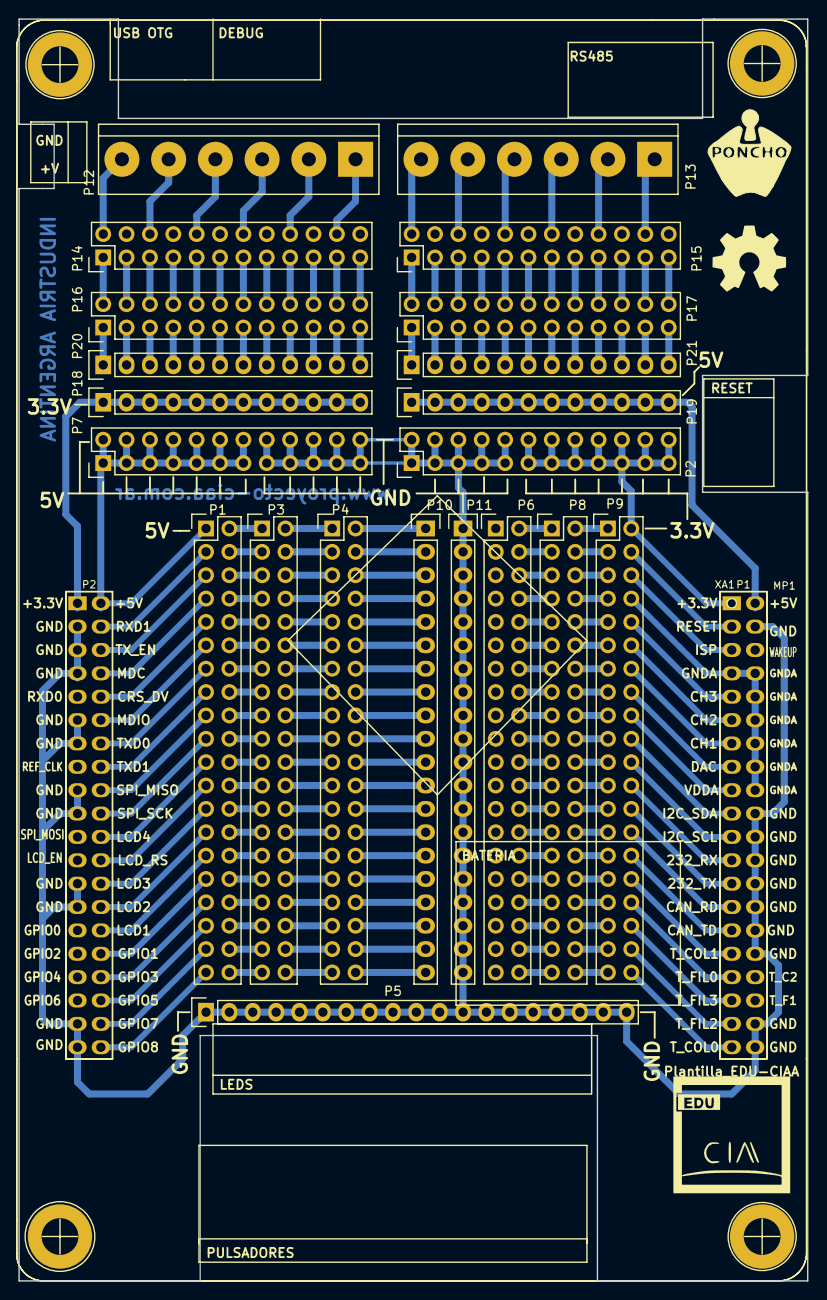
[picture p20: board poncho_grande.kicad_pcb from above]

Board: 2 copper layers, 85.7 x 137.2 mm, 24 parts (0 on the bottom side), 203 nets.

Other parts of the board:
G101: Logo_OSHWA
MP1: Plantilla_EDU-CIAA

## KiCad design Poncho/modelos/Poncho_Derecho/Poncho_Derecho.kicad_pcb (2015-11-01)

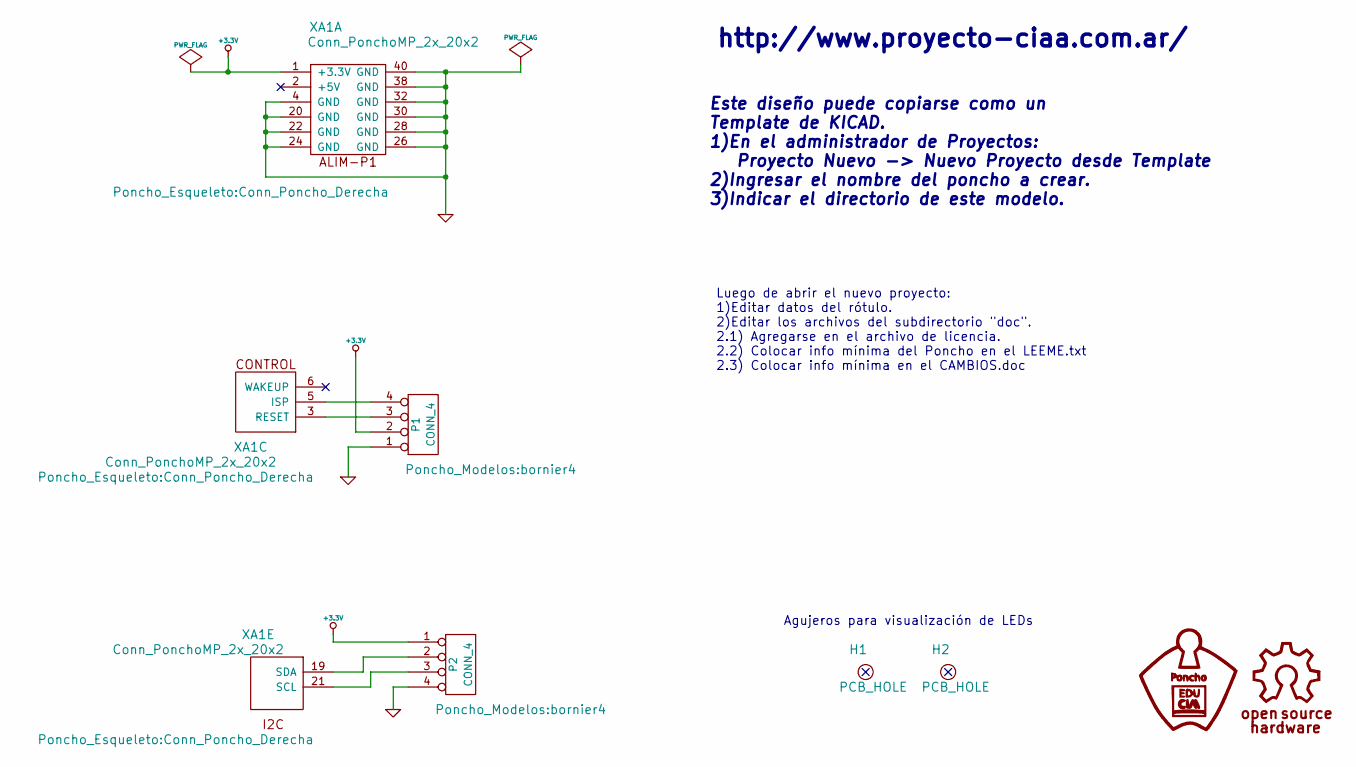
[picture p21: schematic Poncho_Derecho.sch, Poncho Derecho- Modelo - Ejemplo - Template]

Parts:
H1, H2: PCB_HOLE; Led_Hole
P1, P2: CONN_4; bornier4
XA1: Conn_PonchoMP_2x_20x2; Conn_Poncho_Derecha

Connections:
+3.3V: P1.2, P2.1, XA1.1 (+3.3V)
GND: P1.1, P2.4, XA1.4 (GND), XA1.20 (GND), XA1.22 (GND), XA1.24 (GND), XA1.26 (GND), XA1.28 (GND), XA1.30 (GND), XA1.32 (GND), XA1.38 (GND), XA1.40 (GND)
unnamed: P1.3, XA1.3 (RESET)
unnamed: P1.4, XA1.5 (ISP)
unnamed: P2.2, XA1.19 (SDA)
unnamed: P2.3, XA1.21 (SCL)

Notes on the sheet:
Este diseño puede copiarse como un Template de KICAD. 1)En el administrador de Proyectos: Proyecto Nuevo -> Nuevo Proyecto desde Template 2)Ingresar el nombre del poncho a crear. 3)Indicar el directorio de este modelo.
http://www.proyecto-ciaa.com.ar/
Luego de abrir el nuevo proyecto: 1)Editar datos del rótulo. 2)Editar los archivos del subdirectorio "doc". 2.1) Agregarse en el archivo de licencia. 2.2) Colocar info mínima del Poncho en el LEEME.txt 2.3) Colocar info mínima en el CAMBIOS.doc
Agujeros para visualización de LEDs

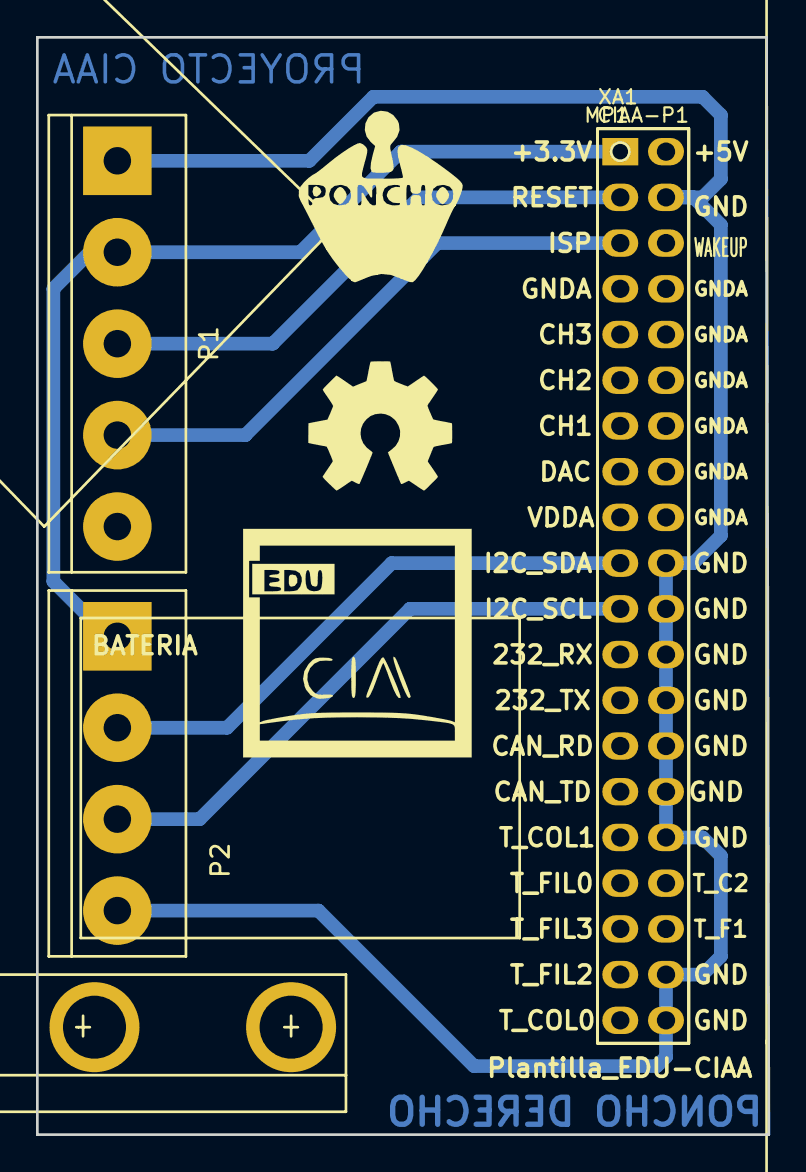
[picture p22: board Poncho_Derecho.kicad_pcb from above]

Board: 2 copper layers, 40.6 x 61.0 mm, 7 parts (0 on the bottom side), 6 nets.

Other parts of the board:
G101: Logo_OSHWA
MP1: Plantilla_EDU-CIAA

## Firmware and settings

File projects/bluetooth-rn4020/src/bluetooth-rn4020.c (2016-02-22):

/* Copyright 2014, Mariano Cerdeiro
 * Copyright 2014, Pablo Ridolfi
 * Copyright 2014, Juan Cecconi
 * Copyright 2014, Gustavo Muro
 *
 * This file is part of CIAA Firmware.
 *
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
 * 3. Neither the name of the copyright holder nor the names of its
 *    contributors may be used to endorse or promote products derived from this
 *    software without specific prior written permission.
 *
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
 */

/*
 * Autores
 * ---------------------------
 * Gabriel Morgillo
 * Nicolás Laurella
 * Alex Muriel
 * Jaime Zubieta Battista
 * Manuel Solito
 */

/*==================[inclusions]==========================*/
#include "os.h"               /* <= operating system header */
#include "ciaaPOSIX_stdio.h"  /* <= device handler header */
#include "ciaaPOSIX_string.h" /* <= string header */
#include "ciaak.h"            /* <= ciaa kernel header */

#include "bluetooth-rn4020.h"         /* <= own header */
#include "rn4020.h"				/* Modulo Bluetooh header */
#include "controlLED.h"			/* Interprete de comandos LED header */



/*==================[macros and definitions]=================================*/
/*==================[internal data declaration]==============================*/
/*==================[internal functions declaration]=========================*/
/*==================[internal data definition]===============================*/

/** \brief File descriptor for digital output ports
 *
 * Device path /dev/dio/out/0
 */
int32_t fd_out;

/** \brief File descriptor for digital output ports
 *
 * Device path /dev/dio/in/0
 */
int32_t fd_in;

/*
 * mantiene el estado de los pulsadores para que funcionen por flanco
 */
static int8_t estado[3];
   
/** \brief File descriptor of the USB uart
 *
 * Device path /dev/serial/uart/1
 */
static int32_t fd_uart1;

/*==================[external data definition]===============================*/
/*==================[internal functions definition]==========================*/
/*==================[external functions definition]==========================*/

/** \brief Main function
 *
 * This is the main entry point of the software.
 *
 * \returns 0
 *
 * \remarks This function never returns. Return value is only to avoid compiler
 *          warnings or errors.
 */
int main(void)
{
   /* Starts the operating system in the Application Mode 1 */
   /* This example has only one Application Mode */
   StartOS(AppMode1);

   /* StartOs shall never returns, but to avoid compiler warnings or errors
    * 0 is returned */
   return 0;
}

/** \brief Error Hook function
 *
 * This fucntion is called from the os if an os interface (API) returns an
 * error. Is for debugging proposes. If called this function triggers a
 * ShutdownOs which ends in a while(1).
 *
 * The values:
 *    OSErrorGetServiceId
 *    OSErrorGetParam1
 *    OSErrorGetParam2
 *    OSErrorGetParam3
 *    OSErrorGetRet
 *
 * will provide you the interface, the input parameters and the returned value.
 * For more details see the OSEK specification:
 * http://portal.osek-vdx.org/files/pdf/specs/os223.pdf
 *
 */
void ErrorHook(void)
{
   ciaaPOSIX_printf("ErrorHook was called\n");
   ciaaPOSIX_printf("Service: %d, P1: %d, P2: %d, P3: %d, RET: %d\n", OSErrorGetServiceId(), OSErrorGetParam1(), OSErrorGetParam2(), OSErrorGetParam3(), OSErrorGetRet());
   ShutdownOS(0);
}

/** Breve descripcion de la funcion inicializacion
 * inicializa el modulo buetooth
 * activa el modo echo
 */
void inicializacion(void){
	   /* send a message to the world :) */
	   char message[] = "\n\rIniciando RN-4020\n\r";
	   ciaaPOSIX_write(fd_uart1, message, ciaaPOSIX_strlen(message));

	   /* RN4020 config. */
	   rn4020_ToggleEcho();
	   rn4020_PartialFactory();
       
       /* Allow some services: Device Information, Battery */
	   rn4020_Write("SS,C0000000\n", 12);
	   
       /** Set features: 
        * Auto Advertise, 
        * Enable MLDP, 
        * Auto MLDP Disable, 
        * Auto-enter MLDP Mode.
        */
       rn4020_Write("SR,38000800\n", 12);
	   
       rn4020_Reboot();
}

/** \brief Initial task
 *
 * This task is started automatically in the application mode 1.
 */
TASK(InitTask)
{
	/* init CIAA kernel and devices */
	   ciaak_start();

	   ciaaPOSIX_printf("Init Task...\n");

	   /* open CIAA digital outputs */
	   fd_out = ciaaPOSIX_open("/dev/dio/out/0", ciaaPOSIX_O_RDWR);

	   /* open CIAA digital inputs */
	   fd_in = ciaaPOSIX_open("/dev/dio/in/0", ciaaPOSIX_O_RDONLY);

	   /* open UART connected to USB bridge (FT2232) */
	   fd_uart1 = ciaaPOSIX_open("/dev/serial/uart/1", ciaaPOSIX_O_RDWR);

	   /* open UART connected to RS232 connector */
	   rn4020_Init();

	   /* configura la UART */
	   ciaaPOSIX_ioctl(fd_uart1, ciaaPOSIX_IOCTL_SET_FIFO_TRIGGER_LEVEL, (void *)ciaaFIFO_TRIGGER_LEVEL3);

	   /*inicializa el modulo */
	   inicializacion();

	   /* Activates the tasks */
	   SetRelAlarm(ActivateButtonsTask, 350, 250);
	   ActivateTask(SerialRXTask);
	   ActivateTask(SerialTXTask);

	   /* end InitTask */
	   TerminateTask();
}

/* Breve descripcion de la funcion SerialRXTask
 *
 * Envia los comandos iniciales al RN4020.
 * Recibe caracteres desde la USB UART y los envia
 * al RN4020.
 */
TASK(SerialRXTask)
{
   int8_t buf[20];   /* buffer for uart operation              */
   int32_t ret;      /* return value variable for posix calls  */

   /* loop infinito */
   while(1) {
	   //lee de UART USB
      ret = ciaaPOSIX_read(fd_uart1, buf, 20);
      if(ret > 0) {
    	  //envia los datos recibidos al modulo
    	  rn4020_Write(buf,ret);
      }
   }
}

/* Breve descripcion de la funcion SerialTXTask
 *
 * Recibe caracteres desde el RN4020 y los envia
 * a la UART USB.
 */
TASK(SerialTXTask)
{
   int8_t buf[20];   /* buffer for uart operation              */
   int32_t ret;      /* return value variable for posix calls  */

   /*loop infinito*/
   while(1)
   {
	   //lee del modulo
      ret = rn4020_Read(buf,20);
      if (ret > 0)
      {
    	  //escribe en UART USB
         ciaaPOSIX_write(fd_uart1, buf, ret);
         //Comprueba si lo que se recibio es un camando del LED
         controlLED_interprete(buf,ret);
      }
   }
}

/* Breve descripcion de la funcion ButtonsTask
 *
 * Realiza un encuestamiento de las entradas digitales.
 * Actualiza los valores de las salidas digitales.
 */
TASK(ButtonsTask)
{
	   uint8_t outputs;
	   uint8_t inputs;

	   //lee los pulsadores
	   ciaaPOSIX_read(fd_in, &inputs, 1);

	   //si hubo un flanco descendente en el interruptor 1
	   if (((inputs&BUTTON1_MASK)==0)&& (estado[0]==0)){
		   /* Conmuta el estado de CMD/MLDP */
		   	 ciaaPOSIX_read(fd_out, &outputs, 1);
		     outputs ^= /*LED1_MASK|*/RN4020_CMD_MLDP_MASK;
		     ciaaPOSIX_write(fd_out, &outputs, 1);
		     estado[0]=1;
	   }
	   else
		   estado[0]=!(inputs&BUTTON1_MASK);

	   //si hubo un flanco descendente en el interruptor 2
	   if (((inputs&BUTTON2_MASK)==0)&& (estado[1]==0)){
		   
           /* Conmuta el estado de WAKE_SW */
		   	 ciaaPOSIX_read(fd_out, &outputs, 1);
		     outputs ^= (RN4020_WAKE_SW_MASK/*|LED2_MASK*/);
		     ciaaPOSIX_write(fd_out, &outputs, 1);
		     estado[1]=1;
	   }
	   else
		   estado[1]=!(inputs&BUTTON2_MASK);

	   //si hubo un flanco descendente en el interruptor 3
	   if (((inputs&BUTTON3_MASK)==0)&& (estado[2]==0)){
		   
           /* Conmuta el estado de WAKE_HW */
		   	 ciaaPOSIX_read(fd_out, &outputs, 1);
		     outputs ^= (RN4020_WAKE_HW_MASK|LED0R_MASK);
		     ciaaPOSIX_write(fd_out, &outputs, 1);
		     estado[2]=1;
	   }
	   else
		   estado[2]=!(inputs&BUTTON3_MASK);

   /* terminate task */
   TerminateTask();
}

/** @} doxygen end group definition */
/*==================[end of file]============================================*/

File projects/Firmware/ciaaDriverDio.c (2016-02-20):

/* Copyright 2014, 2015 Pablo Ridolfi (UTN-FRBA)
 * All rights reserved.
 *
 * This file is part of CIAA Firmware.
 *
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
 * 3. Neither the name of the copyright holder nor the names of its
 *    contributors may be used to endorse or promote products derived from this
 *    software without specific prior written permission.
 *
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
 */

/** \brief CIAA Dio Driver for LPC4337
 **
 ** Implements the Digital Input/Output (Dio) Driver for LPC4337
 **
 **/

/** \addtogroup CIAA_Firmware CIAA Firmware
 ** @{ */
/** \addtogroup Drivers CIAA Drivers
 ** @{ */
/** \addtogroup DIO DIO Drivers
 ** @{ */

/*==================[inclusions]=============================================*/
#include "ciaaDriverDio.h"
#include "ciaaDriverDio_Internal.h"
#include "ciaaPOSIX_stdlib.h"
#include "ciaaPOSIX_string.h"
#include "chip.h"

/*==================[macros and definitions]=================================*/

/** \brief Managed input count */
#define ciaaDriverDio_InputCount (sizeof(ciaaDriverDio_Inputs) / sizeof(ciaaDriverDio_dioType))

/** \brief Managed output count */
#define ciaaDriverDio_OutputCount (sizeof(ciaaDriverDio_Outputs) / sizeof(ciaaDriverDio_dioType))

/** \brief Pointer to Devices */
typedef struct  {
   ciaaDevices_deviceType * const * const devices;
   uint8_t countOfDevices;
} ciaaDriverConstType;

/*==================[internal data declaration]==============================*/

/*==================[internal functions declaration]=========================*/

/*==================[internal data definition]===============================*/

/** \brief PORT/PIN map for managed GPIOs
 *
 * Define port/pin pairs for each GPIO managed by this driver
 */
#if (ciaa_nxp == BOARD)
const ciaaDriverDio_dioType ciaaDriverDio_Inputs[] = { {2,0},{2,1},{2,2},{2,3},{3,11},{3,12},{3,13},{3,14} };
const ciaaDriverDio_dioType ciaaDriverDio_Outputs[] =  { {5,1},{2,6},{2,5},{2,4},{5,12},{5,13},{5,14},{1,8} };
#elif (edu_ciaa_nxp == BOARD)
const ciaaDriverDio_dioType ciaaDriverDio_Inputs[] = { {0,4},{0,8},{0,9},{1,9}, {2,8} };
const ciaaDriverDio_dioType ciaaDriverDio_Outputs[] =  { {5,0}, {0,14},{1,11},{1,12}, {3,3},{3,5},{3,7},{5,15} };
#endif

/** \brief Device for DIO 0 */
static ciaaDevices_deviceType ciaaDriverDio_in0 = {
   "in/0",                          /** <= driver name */
   ciaaDriverDio_open,             /** <= open function */
   ciaaDriverDio_close,            /** <= close function */
   ciaaDriverDio_read,             /** <= read function */
   ciaaDriverDio_write,            /** <= write function */
   ciaaDriverDio_ioctl,            /** <= ioctl function */
   NULL,                           /** <= seek function is not provided */
   NULL,                           /** <= upper layer */
   NULL,                           /** <= layer */
   NULL                            /** <= NULL no lower layer */
};

/** \brief Device for DIO 1 */
static ciaaDevices_deviceType ciaaDriverDio_out0 = {
   "out/0",                          /** <= driver name */
   ciaaDriverDio_open,             /** <= open function */
   ciaaDriverDio_close,            /** <= close function */
   ciaaDriverDio_read,             /** <= read function */
   ciaaDriverDio_write,            /** <= write function */
   ciaaDriverDio_ioctl,            /** <= ioctl function */
   NULL,                           /** <= seek function is not provided */
   NULL,                           /** <= upper layer */
   NULL,                           /** <= layer */
   NULL                            /** <= NULL no lower layer */
};

static ciaaDevices_deviceType * const ciaaDioDevices[] = {
   &ciaaDriverDio_in0,
   &ciaaDriverDio_out0
};

static ciaaDriverConstType const ciaaDriverDioConst = {
   ciaaDioDevices,
   2
};

/*==================[external data definition]===============================*/

/*==================[internal functions definition]==========================*/

/** \brief perform low level gpio initialization for LPC4337
 */
static void ciaa_lpc4337_gpio_init(void)
{
   Chip_GPIO_Init(LPC_GPIO_PORT);

#if (BOARD == ciaa_nxp)
   /* Inputs */
   Chip_SCU_PinMux(4,0,MD_PUP|MD_EZI|MD_ZI,FUNC0); /* GPIO2[0]  */
   Chip_SCU_PinMux(4,1,MD_PUP|MD_EZI|MD_ZI,FUNC0); /* GPIO2[1]  */
   Chip_SCU_PinMux(4,2,MD_PUP|MD_EZI|MD_ZI,FUNC0); /* GPIO2[2]  */
   Chip_SCU_PinMux(4,3,MD_PUP|MD_EZI|MD_ZI,FUNC0); /* GPIO2[3]  */
   Chip_SCU_PinMux(7,3,MD_PUP|MD_EZI|MD_ZI,FUNC0); /* GPIO3[11] */
   Chip_SCU_PinMux(7,4,MD_PUP|MD_EZI|MD_ZI,FUNC0); /* GPIO3[12] */
   Chip_SCU_PinMux(7,5,MD_PUP|MD_EZI|MD_ZI,FUNC0); /* GPIO3[13] */
   Chip_SCU_PinMux(7,6,MD_PUP|MD_EZI|MD_ZI,FUNC0); /* GPIO3[14] */

   Chip_GPIO_SetDir(LPC_GPIO_PORT, 2,0xF, 0);
   Chip_GPIO_SetDir(LPC_GPIO_PORT, 3, 0xF<<11, 0);

   /* MOSFETs */
   Chip_SCU_PinMux(4,8,MD_PUP|MD_EZI,FUNC4);  /* GPIO5[12] */
   Chip_SCU_PinMux(4,9,MD_PUP|MD_EZI,FUNC4);  /* GPIO5[13] */
   Chip_SCU_PinMux(4,10,MD_PUP|MD_EZI,FUNC4); /* GPIO5[14] */
   Chip_SCU_PinMux(1,5,MD_PUP|MD_EZI,FUNC0);  /* GPIO1[8]  */
   Chip_GPIO_SetDir(LPC_GPIO_PORT, 5,(1<<12)|(1<<13)|(1<<14),1);
   Chip_GPIO_SetDir(LPC_GPIO_PORT, 1,(1<<8),1);
   Chip_GPIO_ClearValue(LPC_GPIO_PORT, 5,(1<<12)|(1<<13)|(1<<14));
   Chip_GPIO_ClearValue(LPC_GPIO_PORT, 1,(1<<8));

   /* Relays */
   Chip_SCU_PinMux(4,4,MD_PUP|MD_EZI,FUNC0); /* GPIO2[4] */
   Chip_SCU_PinMux(4,5,MD_PUP|MD_EZI,FUNC0); /* GPIO2[5] */
   Chip_SCU_PinMux(4,6,MD_PUP|MD_EZI,FUNC0); /* GPIO2[6] */
   Chip_SCU_PinMux(2,1,MD_PUP|MD_EZI,FUNC4); /* GPIO5[1] */
   Chip_GPIO_SetDir(LPC_GPIO_PORT, 2,(1<<4)|(1<<5)|(1<<6),1);
   Chip_GPIO_SetDir(LPC_GPIO_PORT, 5,(1<<1),1);
   Chip_GPIO_ClearValue(LPC_GPIO_PORT, 2,(1<<4)|(1<<5)|(1<<6));
   Chip_GPIO_ClearValue(LPC_GPIO_PORT, 5,(1<<1));

   /* LV-TTL GPIOs (not used yet) */
   Chip_SCU_PinMux(6,1,MD_PUP|MD_EZI|MD_ZI,FUNC0); /* GPIO0/P6_1/GPIO3[0] */
   Chip_SCU_PinMux(2,5,MD_PUP|MD_EZI|MD_ZI,FUNC4); /* GPIO1/P2_5/GPIO5[5] */
#elif (BOARD == edu_ciaa_nxp)
   /* Switches */
   Chip_SCU_PinMux(1,0,MD_PUP|MD_EZI|MD_ZI,FUNC0); /* GPIO0[4], SW1 */
   Chip_SCU_PinMux(1,1,MD_PUP|MD_EZI|MD_ZI,FUNC0); /* GPIO0[8], SW2 */
   Chip_SCU_PinMux(1,2,MD_PUP|MD_EZI|MD_ZI,FUNC0); /* GPIO0[9], SW3 */
   Chip_SCU_PinMux(1,6,MD_PUP|MD_EZI|MD_ZI,FUNC0); /* GPIO1[9], SW4 */

   /* PONCHO: gpIo */
   Chip_SCU_PinMux(6,12,MD_PDN|MD_EZI|MD_ZI,FUNC0); /* GPIO2[8], GPIO8 = CTS */

   Chip_GPIO_SetDir(LPC_GPIO_PORT, 0,(1<<4)|(1<<8)|(1<<9),0);
   Chip_GPIO_SetDir(LPC_GPIO_PORT, 1,(1<<9),0);

   Chip_GPIO_SetDir(LPC_GPIO_PORT, 2,(1<<8),0);

   /* LEDs */
   Chip_SCU_PinMux(2,0,MD_PUP|MD_EZI,FUNC4);  /* GPIO5[0], LED0R */
   Chip_SCU_PinMux(2,1,MD_PUP|MD_EZI,FUNC4);  /* GPIO5[1], LED0G */
   Chip_SCU_PinMux(2,2,MD_PUP|MD_EZI,FUNC4);  /* GPIO5[2], LED0B */
   Chip_SCU_PinMux(2,10,MD_PUP|MD_EZI,FUNC0); /* GPIO0[14], LED1 */
   Chip_SCU_PinMux(2,11,MD_PUP|MD_EZI,FUNC0); /* GPIO1[11], LED2 */
   Chip_SCU_PinMux(2,12,MD_PUP|MD_EZI,FUNC0); /* GPIO1[12], LED3 */
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

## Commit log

2015-10-19 Reestructura directorios (sin proyecto kicad)
2015-10-22 Primera footprint
    [Bluetooth_RN4020.kicad_pcb, Bluetooth_RN4020.sch]
2015-10-23 backup pen
    [bluetooth.kicad_pcb, bluetooth.sch, cubec.kicad_pcb]
2015-11-02 Poncho Mediano
    [Bluetooth_RN4020.kicad_pcb]
2015-11-02 Footprint RN4020
    [Bluetooth_RN4020.sch]
2015-11-02 50% Poncho
    [Bluetooth_RN4020.kicad_pcb, Bluetooth_RN4020.sch]
2015-11-09 New Poncho
    [Bluetooth_RN4020.kicad_pcb, Bluetooth_RN4020.sch, bluetooth.kicad_pcb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]
2015-11-09 PCB Completa
    [Bluetooth_RN4020.kicad_pcb, Bluetooth_RN4020.sch]
2015-11-15 Casi listo
    [Bluetooth_RN4020.kicad_pcb, Bluetooth_RN4020.sch]
2015-11-19 Pad Leds
    [Bluetooth_RN4020.kicad_pcb]
2016-02-18 Stable <- Checked
    Un poco de limpieza y de mejora a los comentarios.
2016-02-18 Using GPIOs with POSIX
    Cuando consigamos una configuracion que ande...
    Cleanup de en serio xD
2016-02-18 New header
    Cuando estemos seguro de que todo POSIX anda...
    Dejamos los archivos_DIOasPOSIX como definitivos
2016-02-19 Cleanup. Added more LEDs.
2016-02-20 Footprint acondicionandose
    [Bluetooth_RN4020.kicad_pcb, Bluetooth_RN4020.sch]
2016-02-20 Kicad Fix
    Fix the Kicad
    [Bluetooth_RN4020.kicad_pcb]
2016-02-20 limpieza de codigo
2016-02-20 Error de tipeo
2016-02-20 Jaime was here fixing issues
    [bluetooth-rn4020.c, rn4020.c, rn4020.h]
2016-02-21 Revert "xto18. Fix1"
    This reverts commit dbc30a1bce1aaf387efd1c8ba1701ec3e7147f4f.
    [rn4020.c]
2016-02-21 Revert "xtoa8. Untested."
    This reverts commit 4b30420bb6128e25abb3a8a6a892bd2772da7d83.
    [rn4020.c]
2016-02-21 Revert "Nombre TASK"
    This reverts commit cbe7e4abbd0df764d3527fef311c0dc05d90ac37.
    [bluetooth-rn4020.c, rn4020.c, rn4020.h]
2016-02-21 Revert "Jaime was here fixing issues"
    This reverts commit b2956c1b9d9feeac712582e668425a70073c5619.
    [bluetooth-rn4020.c, rn4020.c, rn4020.h]
2016-02-21 Revert "Using HEADER-MK2. (hopefully will work)"
    This reverts commit 9fa9ac7b7040349473408e8b42816d540d1fc3b2.
    [bluetooth-rn4020.c, rn4020.c, rn4020.h]
2016-02-21 Revert "Revert "Using HEADER-MK2. (hopefully will work)""
    This reverts commit 16b3b15d7d406d38b6dea693941feadd3e67cc50.
    [bluetooth-rn4020.c, rn4020.c, rn4020.h]
2016-02-21 Revert "Revert "Jaime was here fixing issues""
    This reverts commit b4e396c0dba5dbc416c620b5a40368b85dc9dbd5.
    [bluetooth-rn4020.c, rn4020.c, rn4020.h]
2016-02-21 Revert "Revert "xtoa8. Untested.""
    This reverts commit 957a1962c80c74f2c578f37da13fc5a940c7073c.
    [rn4020.c]
2016-02-21 Revert "Revert "xto18. Fix1""
    This reverts commit 43435aa63cad0025363222c446debc3481fc0273.
    [rn4020.c]
2016-02-21 Revert "Revert "Revert "xto18. Fix1"""
    This reverts commit 75955d8e49eb79a8957352ffa191ceb1c78391b6.
    [rn4020.c]
2016-02-21 Revert "Revert "Revert "xtoa8. Untested."""
    This reverts commit 6411236e90ae7b95fa09032d08748df4bc0d5537.
    [rn4020.c]
2016-02-21 Revert "Revert "Revert "Jaime was here fixing issues"""
    This reverts commit 679956b0d82bb61afe1a5013e9482ba39d32765a.
    [bluetooth-rn4020.c, rn4020.c, rn4020.h]
2016-02-21 Revert "Revert "Revert "Using HEADER-MK2. (hopefully will work)"""
    This reverts commit 05bf12efe6998f2855171859b334fe12807c4bda.
    [bluetooth-rn4020.c, rn4020.c, rn4020.h]
2016-02-21 Mas comentarios.
    +minor fix
    [bluetooth-rn4020.c, rn4020.c, rn4020.h]
2016-04-15 Added Android Project
    Can switch state of LED1, LED2 and LED3
2016-04-16 Added LED0 Commands
    Hay que acomodar el repo para que ignore los archivos locales para
    buildear... Arma lio sino.
